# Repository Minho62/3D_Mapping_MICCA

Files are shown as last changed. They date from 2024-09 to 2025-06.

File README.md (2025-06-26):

# 3D라이다를 활용한 지형 측량 디바이스

## 목차
1. [프로젝트 소개](#프로젝트-소개)
2. [개발환경](#개발환경)
3. [DIRECTORY TREE](#directory-tree)
4. [주요 함수별 기능](#주요-함수별-기능)
5. [Flow chart](#flow-chart)
6. [H/W](#hw)
7. [F/W](#fw)
8. [SW구성](#sw구성)
9. [기능설계도](#기능설계도)
10. [RESULT](#result)

----------

## 프로젝트 소개
- 이 디바이스는 3D라이다(LIDAR)와 관성측정장치(IMU)를 활용하여 지형 데이터를 수집하는 혁신적인 도구입니다. 이를 통해 정확하고 상세한 지형 정보를 제공합니다. 디바이스는 두 가지 측정 방식을 지원합니다.
    - 2D 단면 데이터 측정: 라이다 센서를 통해 특정 단면의 2차원 데이터를 수집하여 해당 구역의 상세한 정보를 제공합니다. 이는 특정 구역의 높낮이와 형태를 명확하게 파악하여 2D 도면으로 나타내어 줍니다.
    - 3D 데이터 측정: 라이다와 IMU를 결합하여 지형의 3차원 데이터를 생성합니다. 이를 통해 지형의 전체적인 구조와 특징을 입체적으로 파악할 수 있습니다. 필요시, 해당 공간의 체적을 구할 수 있습니다.
- 또한, 디바이스는 두 가지 모드로 측정을 수행할 수 있습니다.
    - 차량 모드: 디바이스를 4륜 차량에 장착하여 블루투스로 조작할 수 있습니다.
    - 셀카 모드: 좁은 내부 공간 등 차량이 들어가기 어려운 구역을 사람이 직접 손으로 들고 측정할 수 있습니다.
- 이 디바이스는 건설, 토목 공사, 상하수도 점검, 아파트(오피스텔) 내부 측량 등에 활용될 수 있습니다.

https://github.com/user-attachments/assets/129de977-cf51-411d-8989-09c48eeaee29

----------

## 개발환경
- OS: Window10, Ubuntu 20.04, ROS Noetic
- Tool: VScode, JupyterNotebook, Arduino
- 프로젝트 관리:Notion, Github
- 회로: OrCad Capture
- PCB: PADS Layout

----------

## DIRECTORY TREE
```
.
├─Atmel/
│  ├─car/
│  │      car.ino
│  └─control_box/
│         control_box.ino
├─catkin_ws/
│  └─src/
│      ├─LIO-SAM-master/
│      ├─velodyne/
│      └─xsens_ros_mti_driver/
├─circuit/
├─doc/
├─img/
├─modeling/
└─source/
    │  main_3.py
    ├─CloudPoint2CAD/
    │  │  CloudPoint2CAD.ipynb
    │  └─USB/
    │      └─LOAM_PCD/
    ├─CloudPoints_representative_value/
    │     CloudPoints_representative_value.md
    ├─log/
    ├─USB/
    ├─volume/
    └─    volume.py

```

각 폴더와 파일에 대한 개요입니다:

| 폴더, 파일 | 설명 |
| --- | --- |
| `Atmel/` | Jetson Orin Nano와 통신, XM430-W210-T(모터), Control Box, 4륜 자동차, Atmega2560을 제어하기 위한 Atmel 소스 |
| `car.ino` | 4륜 자동차 제어를 위한 소스 |
| `control_box.ino` | Control Box를 이용해 Jetson Orin Nano와 Serial 통신을 위한 소스 |
| `catkin_ws/` | ROS Workspace|
| `src/` | ROS Workspace의 src 폴더 |
| `LIO-SAM-master/` | 3D Mapping을 위한 LIO SAM 알고리즘 |
| `velodyne/` | VLP-16(Lidar)을 사용하기 위한 소스 |
| `xsens_ros_mti_driver/` | XSENSE MTi-G-710-6A8G4(IMU)를 사용하기 위한 소스 |
| `circuit/` | F/W를 제어하기 위한 회로도 |
| `doc/` | 참고한 데이터셋, 자료 |
| `img/` | 프로젝트 수행 이미지 |
| `modeling/` | 모델링 이미지 |
| `source/` | 3D Mapping, 측정 데이터 처리를 위한 폴더 |
| `mian_3.py` | 3D Mapping, 측정 데이터 처리를 위한 소스 |
| `CloudPoint2CAD/` | Cloud Point를 CAD파일로 변환, 테스트 폴더 |
| `CloudPoint2CAD.ipynb` | 수집한 Cloud Point를 2D 단면으로 나타내 DXF 파일로 변환하는 소스 |
| `CloudPoints_representative_value/` | 3D Mapping 후 Cloud Points 전처리 자료 |
| `CloudPoints_representative_value.md` | 3D Mapping 후 CloudCompare를 활용한 Cloud Points의 대표 좌표값 추출 방법|
| `log/` | 'mian_3.py'의 log |
| `USB/` | 기록된 Ros Bag 파일, Cloud Point data, 데이터 처리 파일을 저장하기 위한 경로(삽입한 USB 경로) |
| `volume/` | 3D체적을 구하는 경로 |
| `volume.py` | Cloud Points의 대표 좌표값 추출 후 3D 체적을 구하는 소스 |

----------

## 주요 함수별 기능
### main_3.py

| 함수, 클래스 | 설명 |
| --- | --- |
| `SERIAL` | 시리얼 포트를 통해 JetsonOrinNano와 Arduino간의 통신을 관리 |
| `socket_isOpen` | 지정된 호스트(Lidar VLP16)가 네트워크에서 활성 상태인지 확인하여, 연결 가능하면 True를 반환|
| `read_6D_PCDFile` | 맵핑 이후, PCD 파일을 읽어 XYZ 좌표, 강도(intensity), 회전(roll, pitch, yaw) 및 시간을 배열로 반환 |
| `slice_points2img` | 3D 포인트 클라우드를 주어진 평면의 법선 벡터에 투영하여 2D 평면에 XY 좌표로 변환한 배열을 반환 |
| `LIO_SAM` | LIO-SAM 프로세스를 관리하고 데이터를 처리, 여러 측정 모드들을 실행시키고 관리 |
| `change_lio_param` |  LIO-SAM의 설정 파일을 수정하여 PCD 파일 저장 위치를 업데이트 |
| `stop` | 현재 실행 중인 LIO-SAM 및 ROS BAG 프로세스를 중지 |
| `send_process_data` | 현재 프로세스의 진행 상태를 시리얼로 전송 |
| `cave_mode` | 동굴(CAVE) 측정 모드(모든 진행경로를 Mapping하는 모드)에서 데이터를 처리하고 ROS BAG 기록을 시작 |
| `processing` | 터널(TUNNEL) 측정 모드(측정 장비를 90도로 회전 후, 평면을 Scan하는 모드)에서 ROS BAG 기록을 시작 후 3D 좌표 데이터를 처리하여 2D로 나타냄 |
| `SERIAL_DATA_PROC` | 시리얼 데이터를 분석하여 상태를 업데이트하고, 들어오는 명령을 처리 |
| `SBC_CONTROL` | JetsonOrinNano, Arduino, LiDAR, IMU, Battery, USB 장치의 연결 상태를 모니터링하고, 필요에 따라 해당 장치와 상호작용 |
| `get_usb_stat` | 연결된 USB 장치의 정보를 반환 |
| `is_usb_device` | 주어진 장치가 USB 장치인지 확인하고, USB 장치일 경우 True를 반환 |
| `new_get_mount_points` | 현재 마운트된 USB 장치들의 정보를 반환 |\
| `arduino` | 아두이노 장치를 탐색하여 연결하고, 상태를 업데이트 |
| `lidar` | LiDAR 장치의 네트워크 연결 상태를 확인하고, 연결 여부에 따라 ROS 노드를 실행 또는 종료 |
| `imu` | IMU 장치의 USB 연결 상태를 확인하고, 연결 여부에 따라 ROS 노드를 실행 또는 종료 |
| `search_usb` |  USB 장치의 연결 상태를 확인하고, 아두이노에 USB 연결 상태를 알림 |
| `mount_usb` | 시스템에 연결된 USB 장치를 마운트 |
| `umount_usb` |  시스템에서 USB 장치를 언마운트하고 안전하게 연결을 해제 |
| `emergency_stop` | 비상 정지 명령이 내려졌을 때, 모든 프로세스를 종료하고 시스템을 셧다운 |
| `state` |  LiDAR, IMU, USB 장치가 모두 연결되어 있는지 상태를 반환 |

----------

## Flow chart
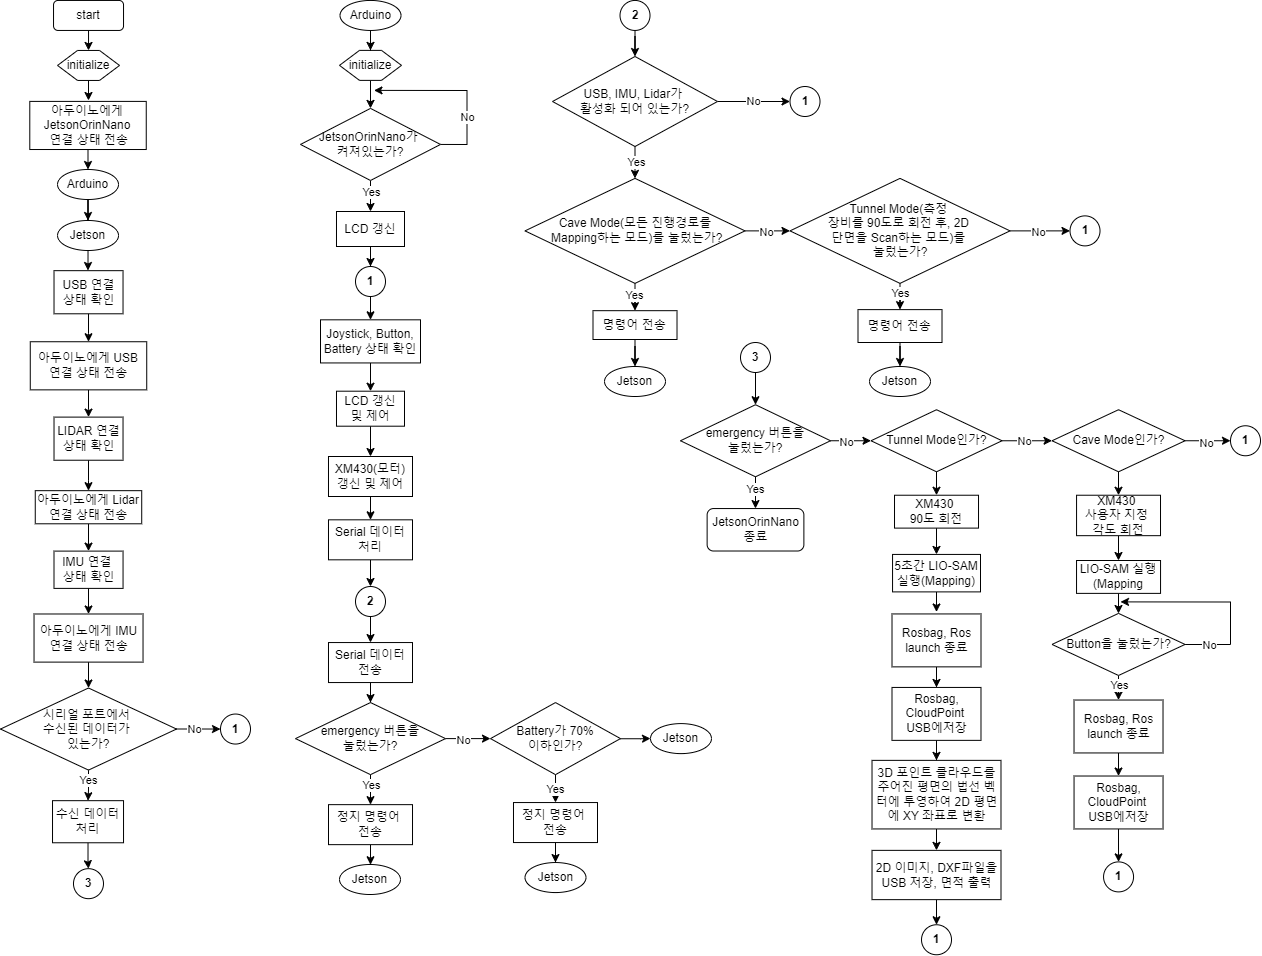
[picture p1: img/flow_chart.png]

  
----------

## H/W
- Fusion 360을 통해 모델링
- 3D 프린터를 통해 제작

MODELING             |  REAL
:-------------------------:|:-------------------------:
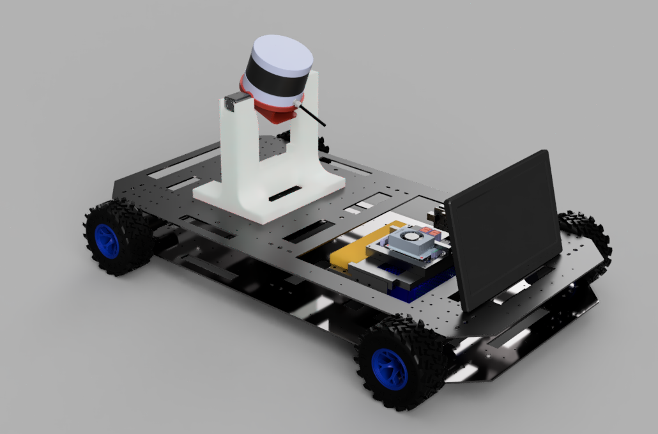
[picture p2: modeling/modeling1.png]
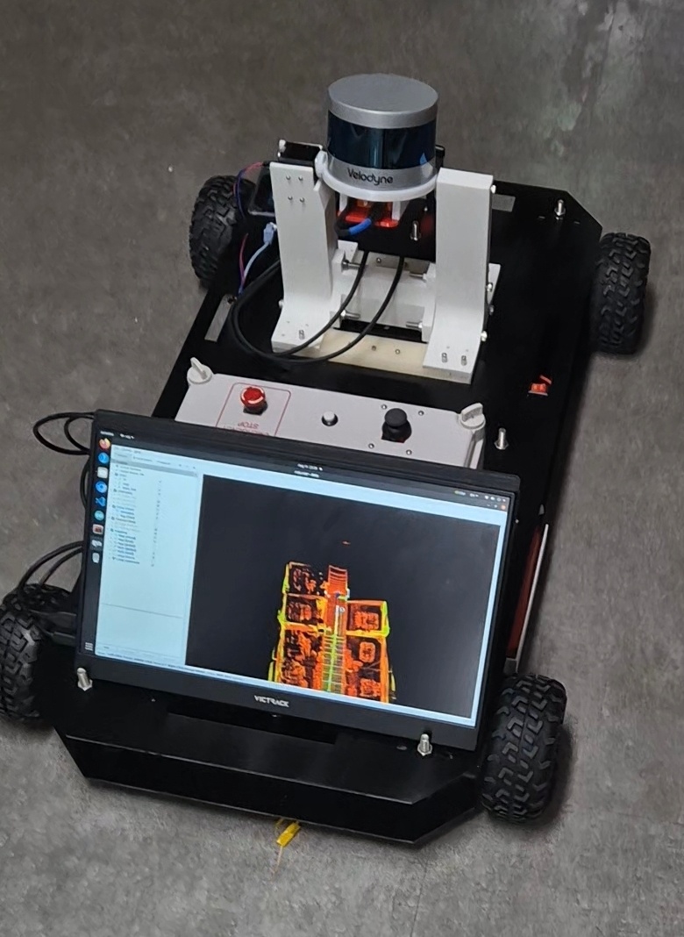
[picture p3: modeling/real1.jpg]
  |  
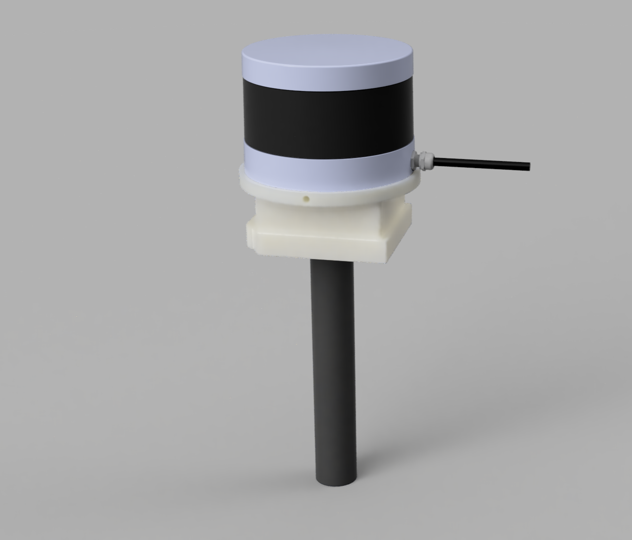
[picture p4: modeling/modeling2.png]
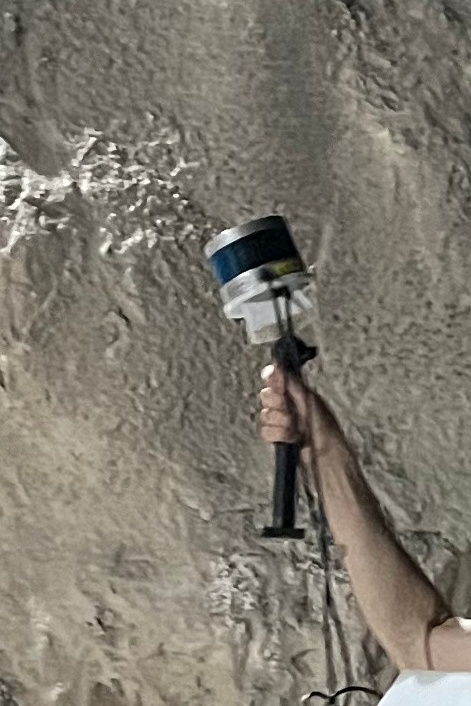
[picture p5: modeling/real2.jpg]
  |  
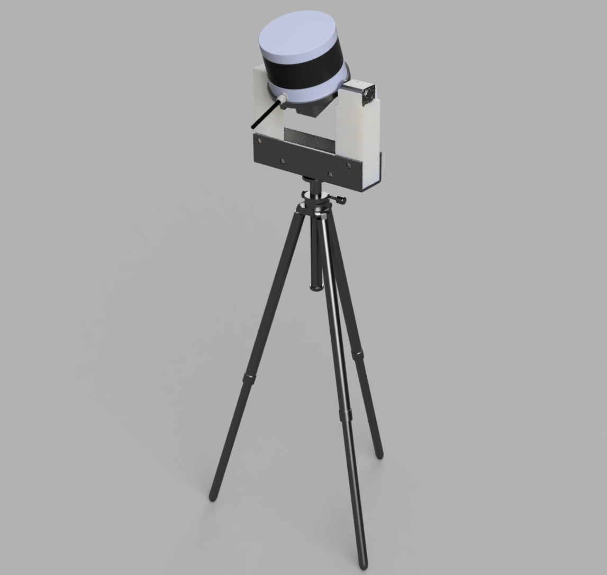
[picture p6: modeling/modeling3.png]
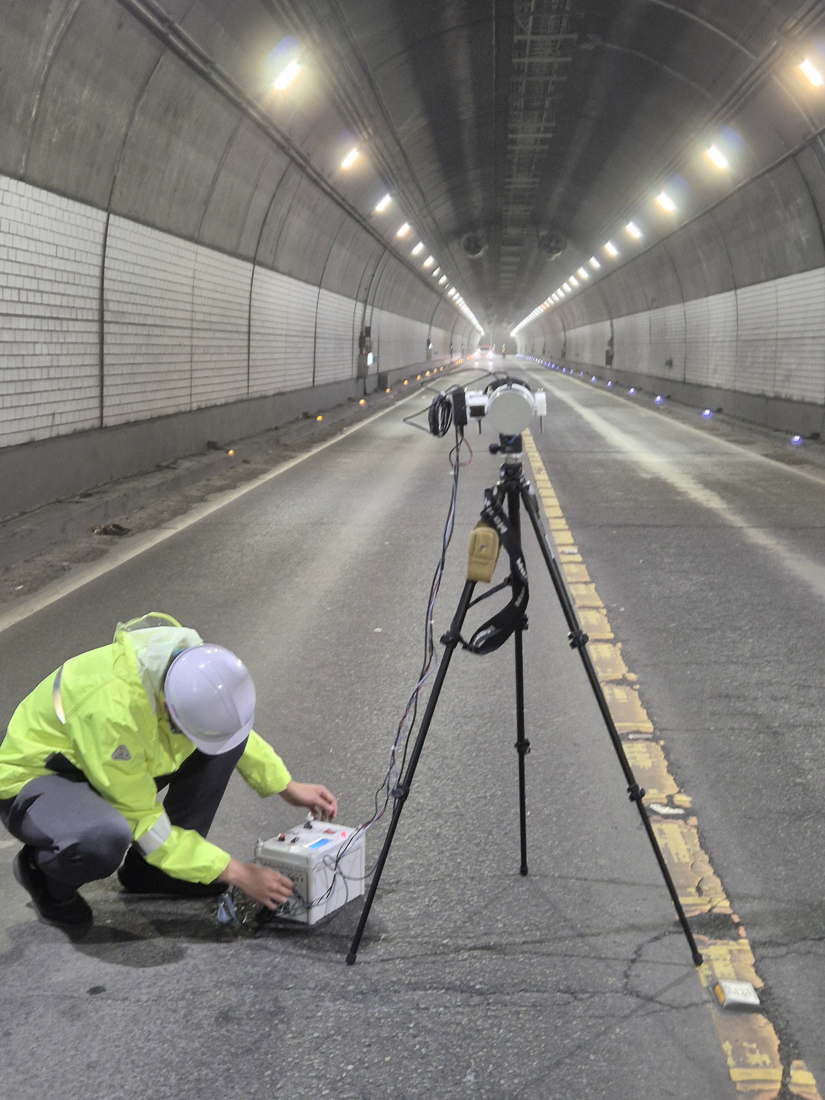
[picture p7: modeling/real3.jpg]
  |  

----------

## F/W
- 블럭도
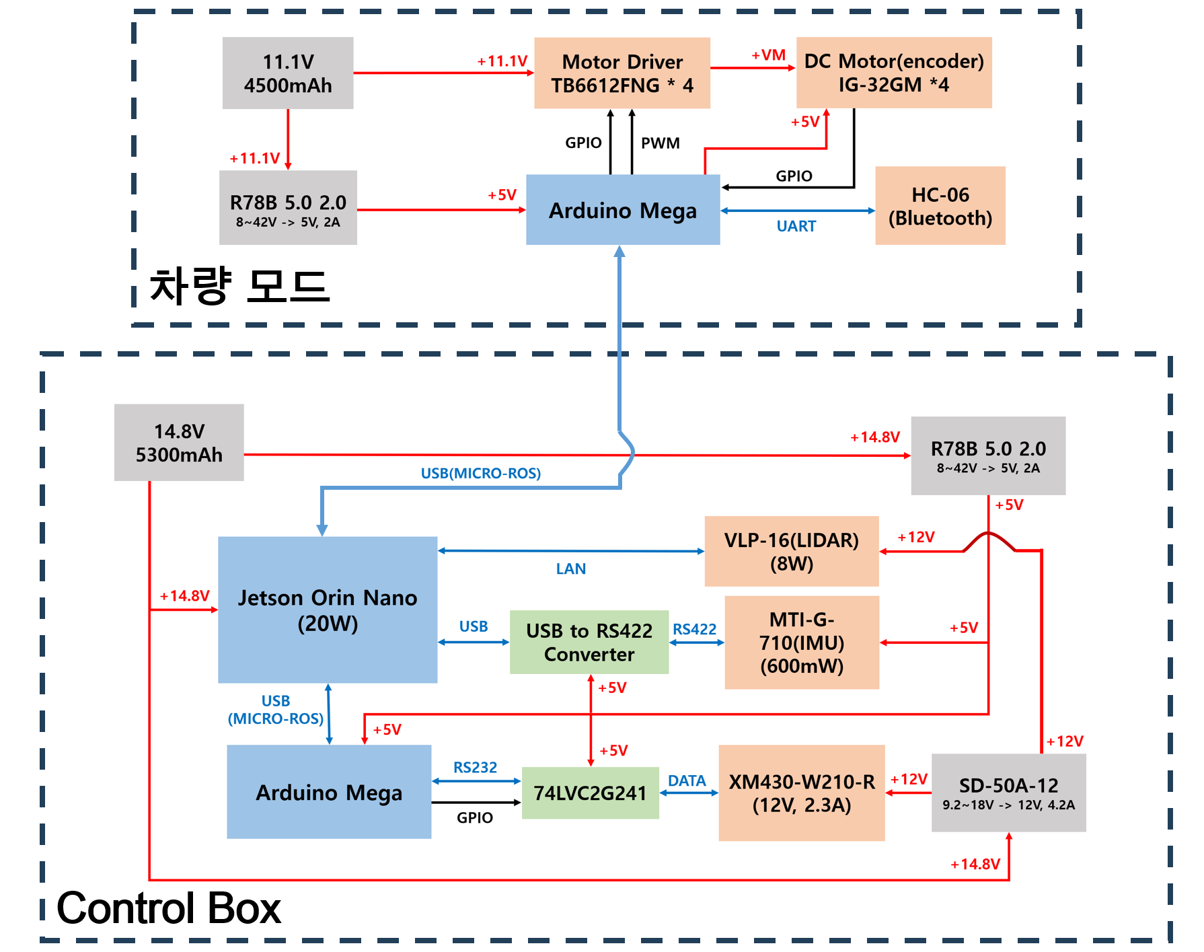
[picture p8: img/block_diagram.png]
    

- Control Box
    - 회로도
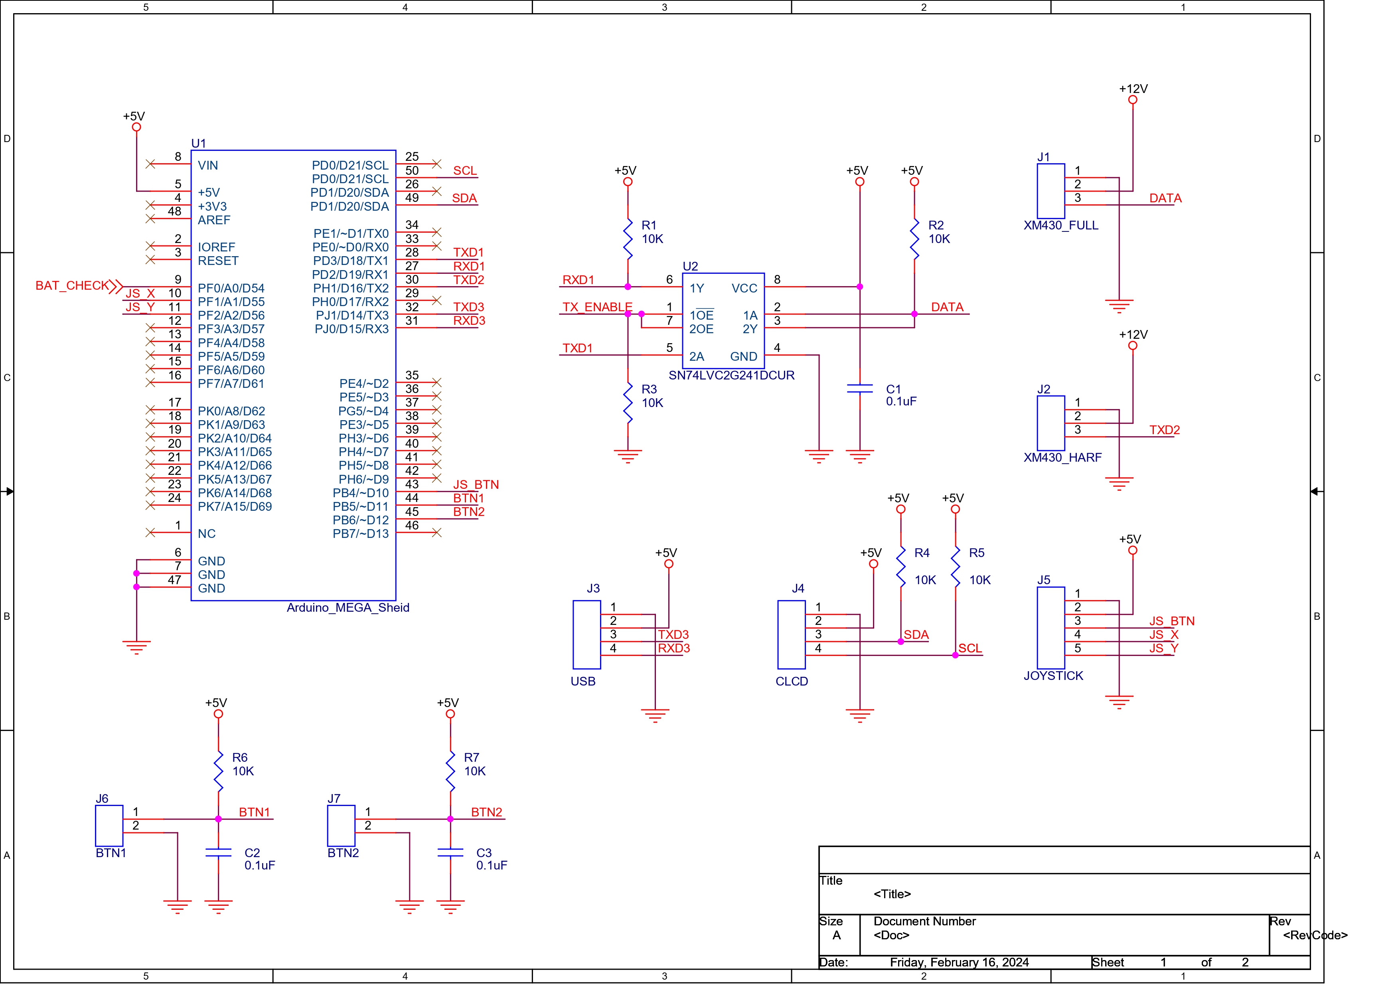
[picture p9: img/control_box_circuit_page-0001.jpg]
        
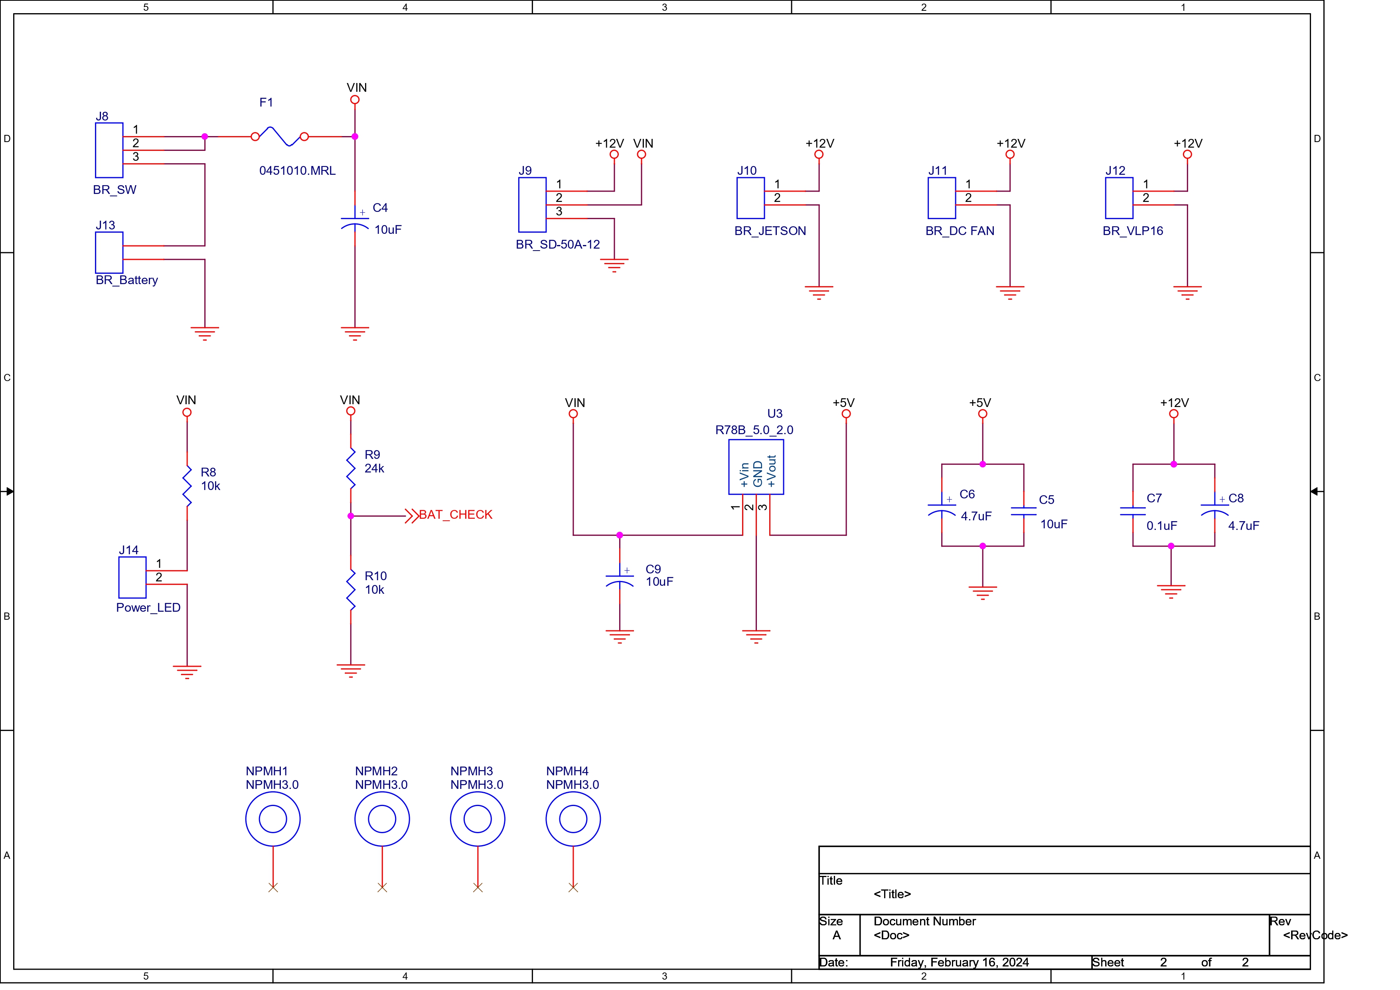
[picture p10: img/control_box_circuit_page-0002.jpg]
        
    - PCB
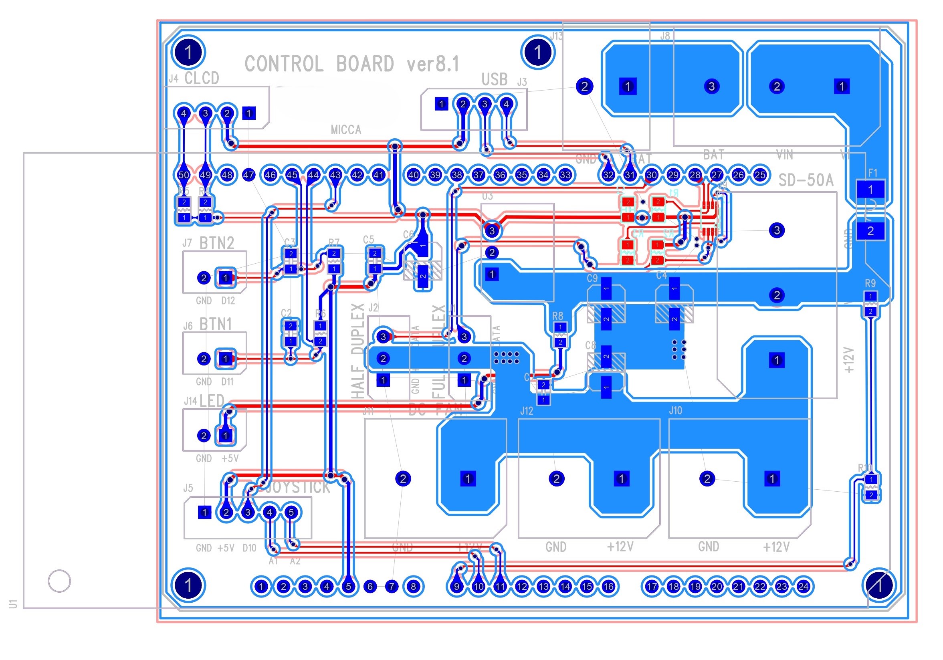
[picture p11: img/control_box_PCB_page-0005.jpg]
        
- 차량 모드
    - 회로도
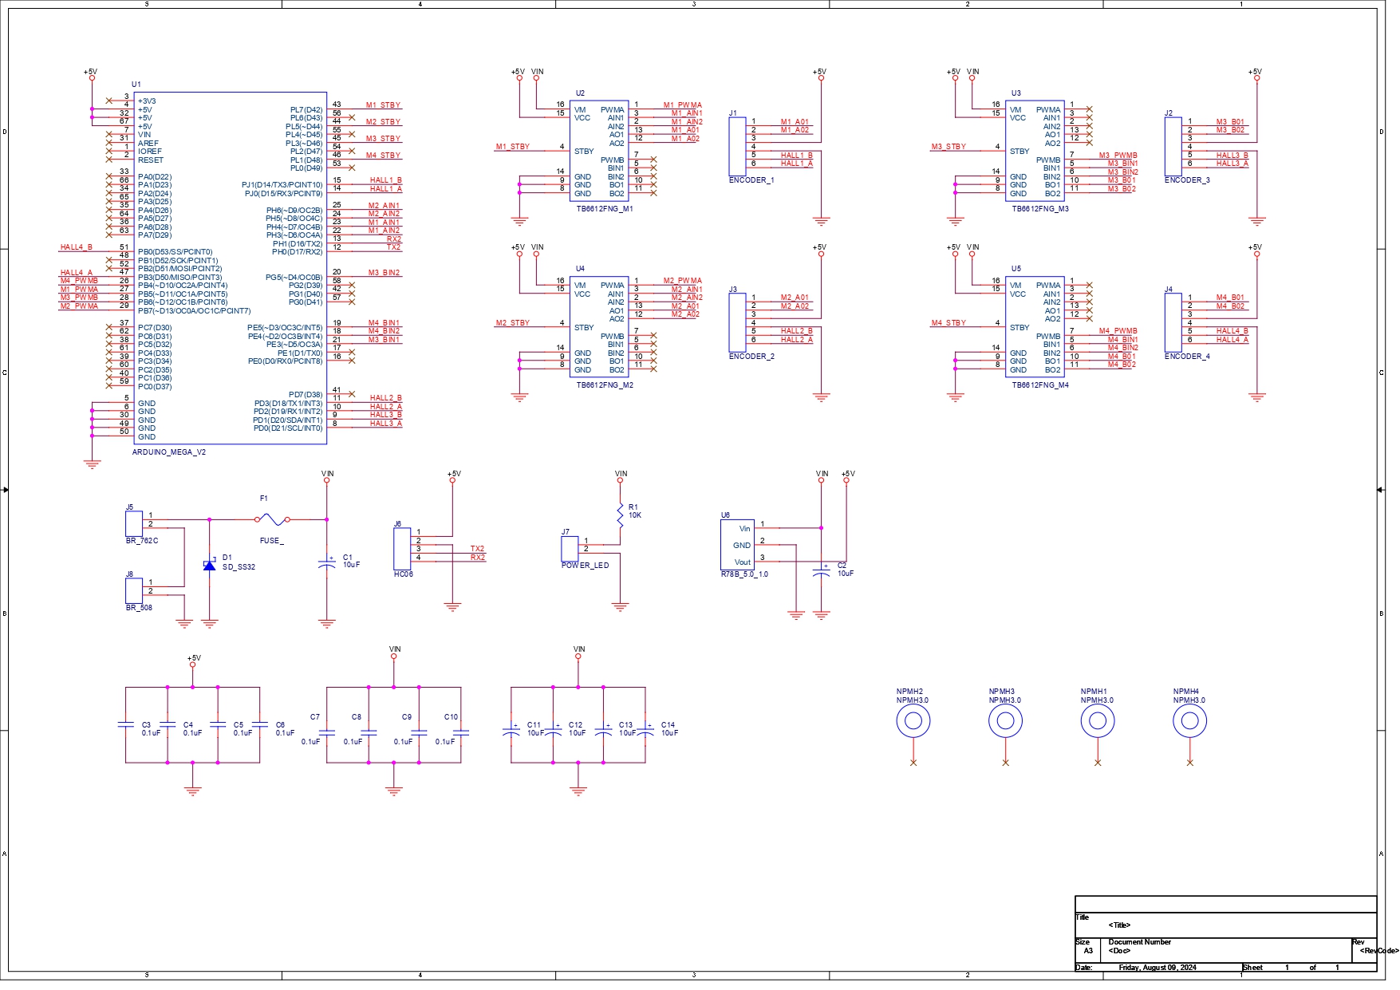
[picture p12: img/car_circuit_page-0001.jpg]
        
    - PCB
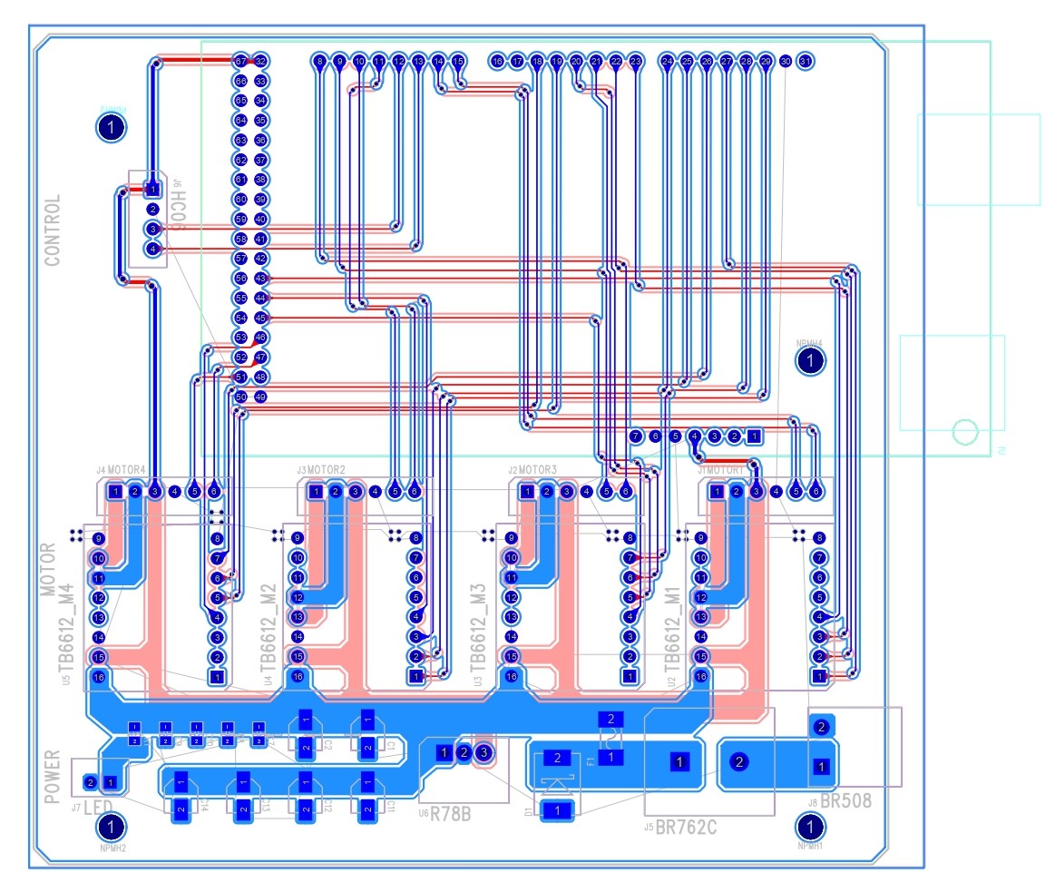
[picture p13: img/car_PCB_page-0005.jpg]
        

----------

## S/W구성
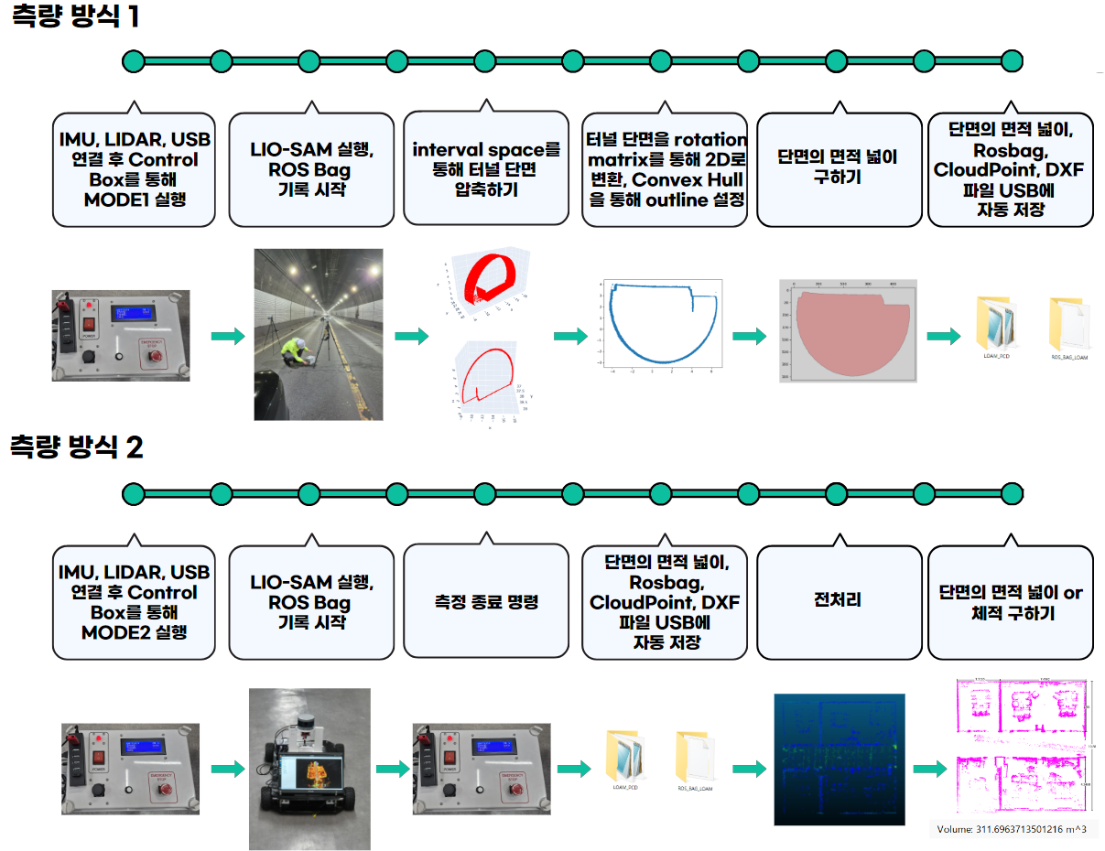
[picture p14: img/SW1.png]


----------

## 기능설계도
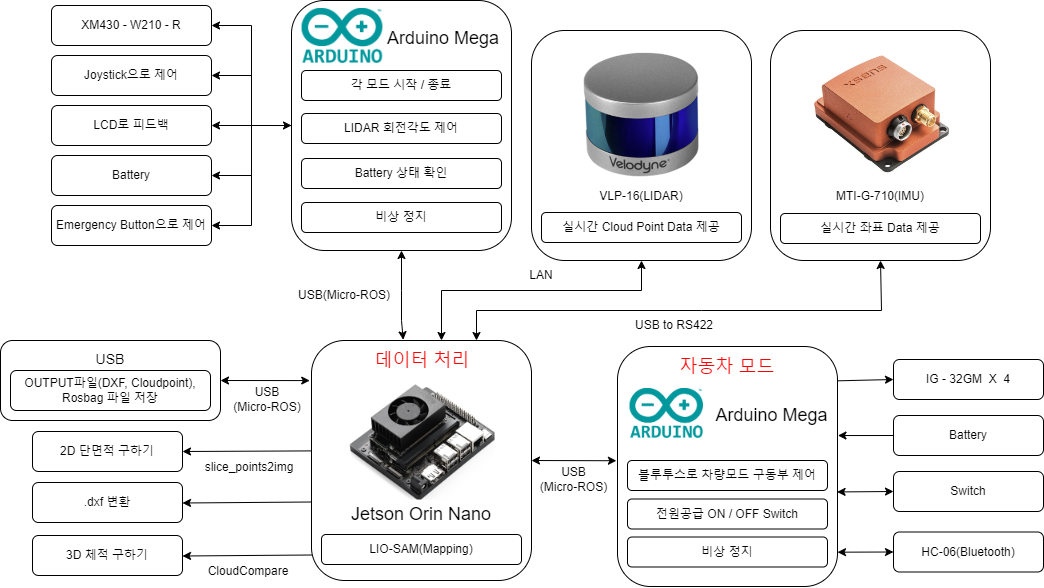
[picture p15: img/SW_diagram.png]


----------

# RESULT

## Tunnel

Real             |
:-------------------------:|
 |

Scan             |  DXF
:-------------------------:|:-------------------------:
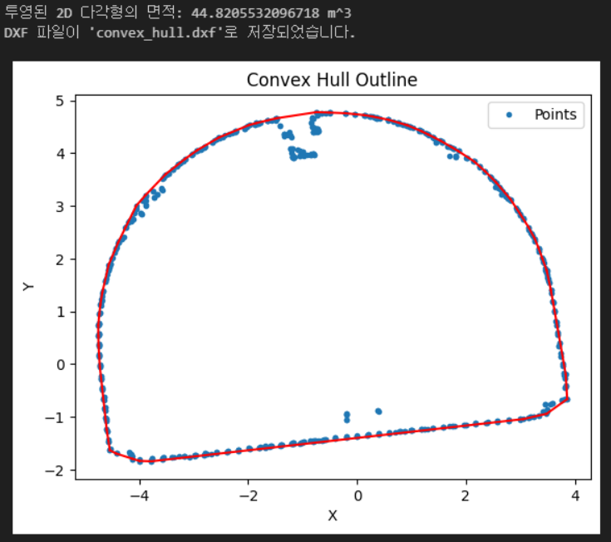
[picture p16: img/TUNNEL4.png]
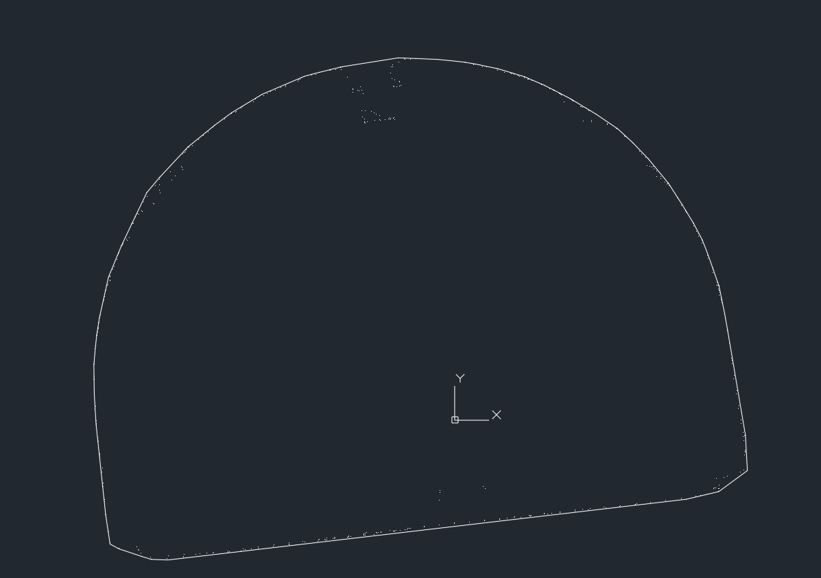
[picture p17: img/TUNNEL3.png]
  |  

----------

## Cave

Real            |  Scan
:-------------------------:|:-------------------------:
<video src = "https://github.com/user-attachments/assets/7dc2f852-dbb4-49e8-8e83-06cb473ff6c9"> |  <video src = "https://github.com/user-attachments/assets/3b821411-f0cc-4dca-8465-04873961ad4c" width="20%" height="20%"> 

----------

## 건축물 2D 단면

Real             |
:-------------------------:|
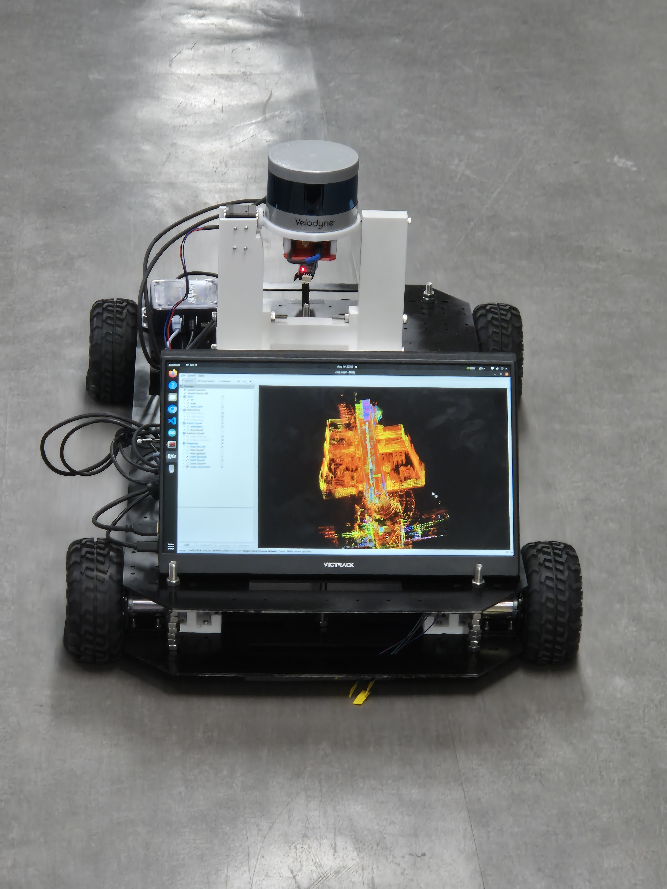
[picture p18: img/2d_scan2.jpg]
 |

실제 설계 단면             |  Scan
:-------------------------:|:-------------------------:
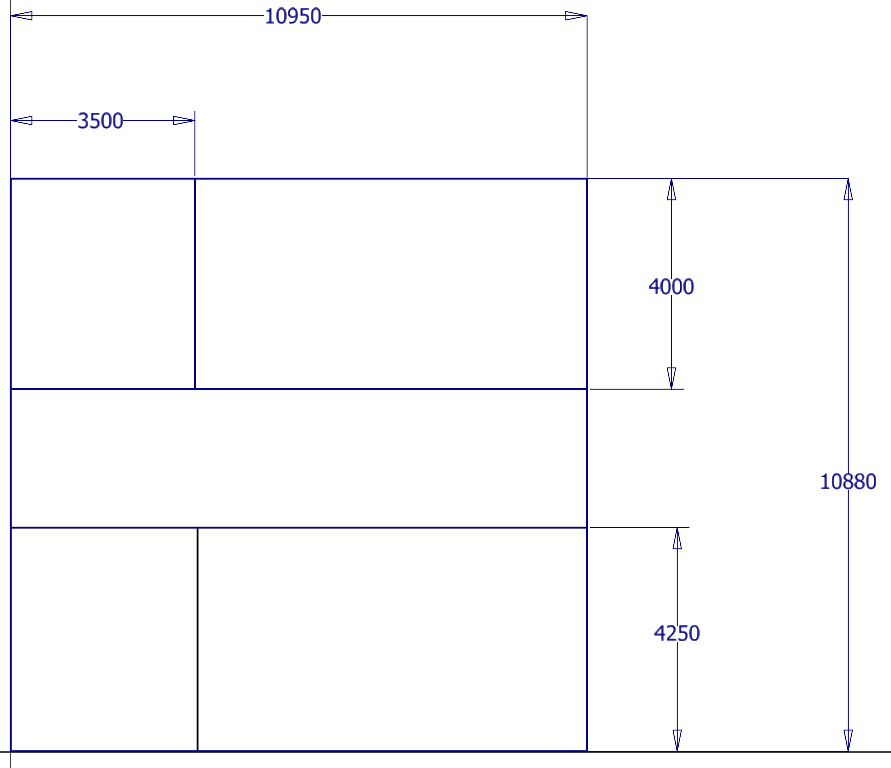
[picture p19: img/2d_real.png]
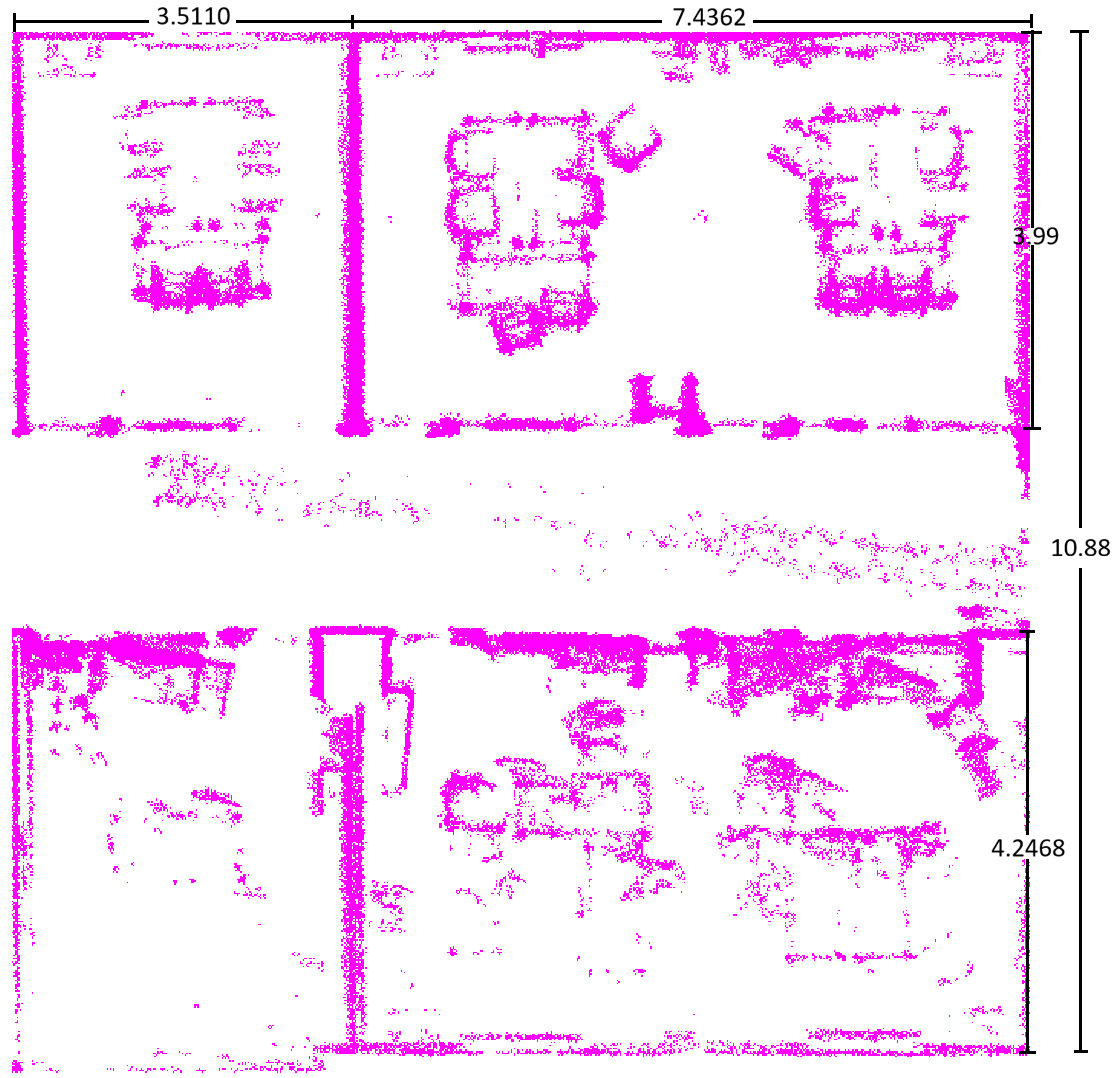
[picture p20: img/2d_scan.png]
  |  
실제 설계 넓이 : 119.136㎡	 |  Scan 넓이 : 119.09248㎡

오차율 : 0.037% 

----------

## 건축물 3D 체적

Real             |
:-------------------------:|
 |

실제 설계 단면             |  Scan
:-------------------------:|:-------------------------:
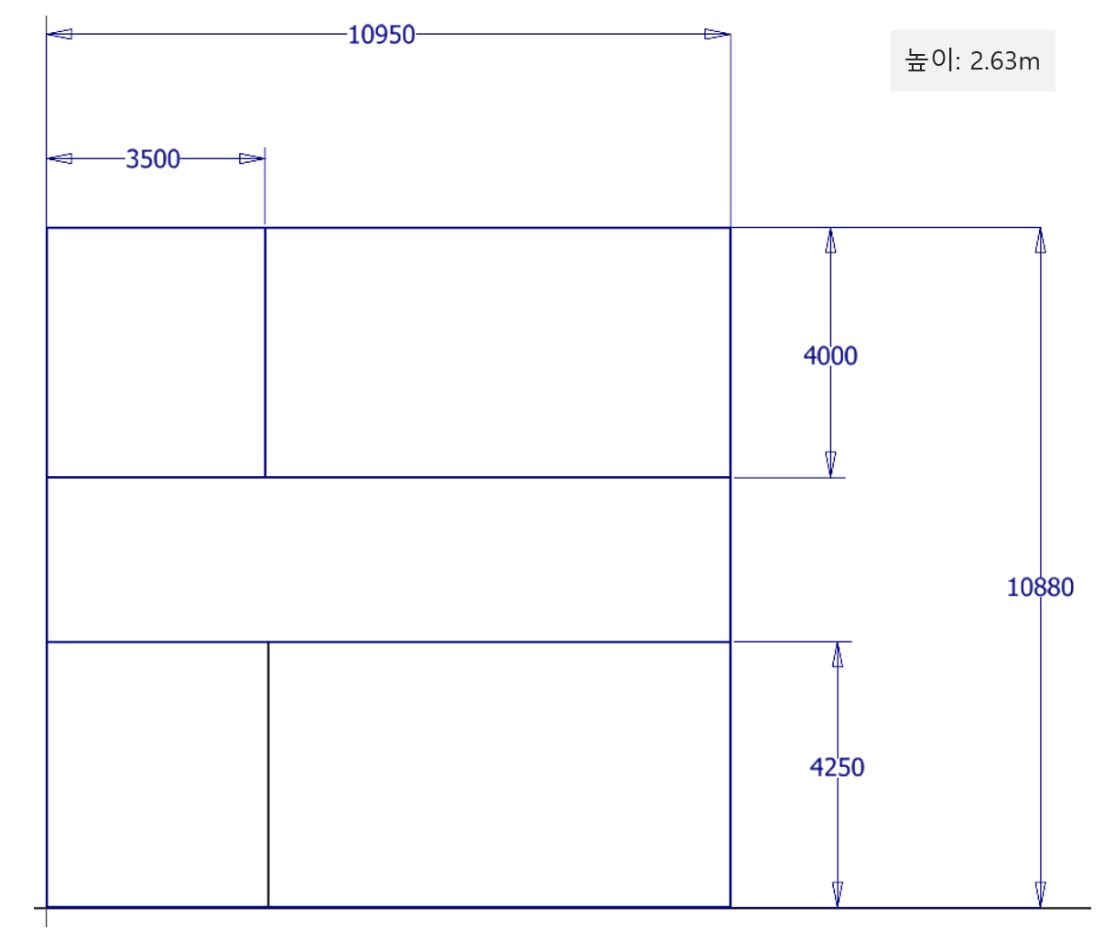
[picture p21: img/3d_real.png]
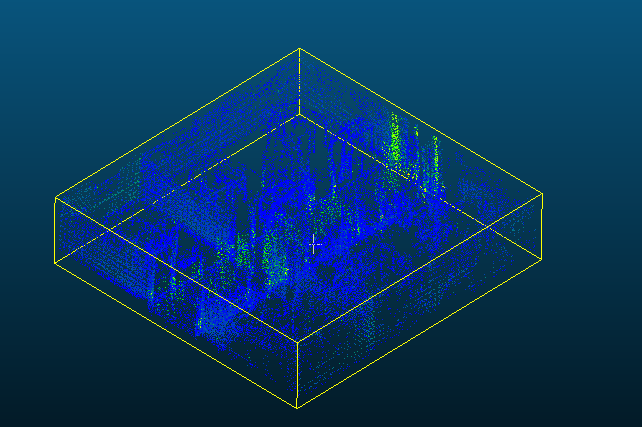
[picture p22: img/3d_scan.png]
  |  
실제 설계 체적 : 313.32768m³	 |  Scan 체적 : 311.6963713501216m³

오차율 : 0.523%

----------

## Road

Real            |  Scan
:-------------------------:|:-------------------------:
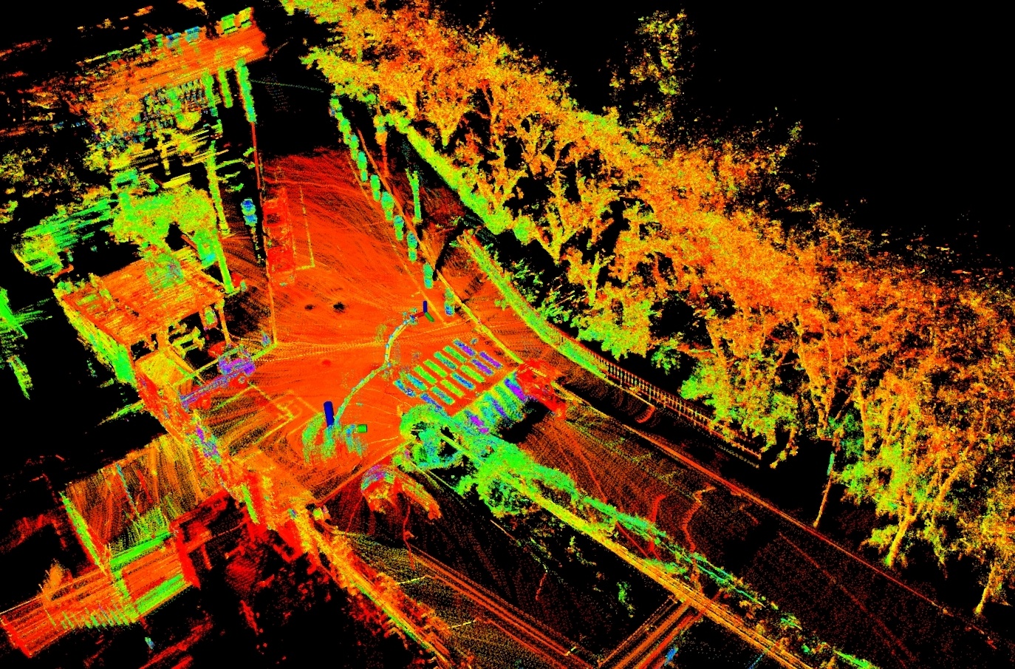
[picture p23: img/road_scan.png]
<video src = "https://github.com/user-attachments/assets/0827d623-0713-4f08-83b8-101b94800f4f"> |   

----------

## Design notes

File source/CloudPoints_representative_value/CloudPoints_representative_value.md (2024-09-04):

# CloudCompare를 활용한 대표 좌표값 추출 방법(전처리)

 **이민호**

[CloudCompare v2.6.1 - User manual.pdf](CloudPoints_representative_value/CloudCompare_v2.6.1_-_User_manual.pdf)

---

1. 파일 ➡️ 열기 ➡️ ‘cloudGlobal.pcd’ **파일 열기**

---

1. **좌표 축 정렬**
우측 하단 밑의 좌표계 참고 → 포인트들의 좌표 축이 정렬되어 있지 않음
    
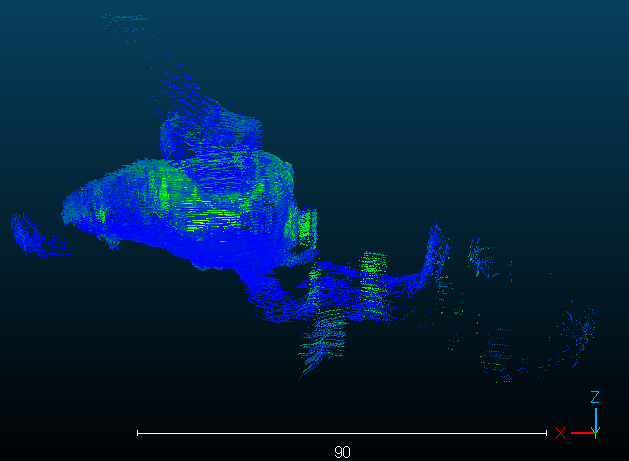
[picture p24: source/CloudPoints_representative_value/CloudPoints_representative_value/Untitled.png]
    
    
    ➡️ 구름 아이콘 클릭 
    
    
    
    ➡️ 상단 메뉴 바에서 회전 클릭
    
    
    
    ➡️ 좌측 메뉴 바에서 도형을 클릭하면 내가 원하는 평면을 볼 수 있게 해줌.
    
    
    
    ➡️ 각각의 평면을 확인하고, 회전하고자 하는 축을 선택
    ➡️ 축 선택 후 회전 각도 입력( 많이 회전 → 큰 각도 / 정밀하게 → 작은 각도)
    
    윗칸 회전      :  축 회전
    아랫칸 회전  :  평면 이동
    
    ➡️ 백워드 or 전방을 눌러 회전시켜 회전 축을 정렬한다. 마우스로도 회전 가능
    
    ➡️ 정렬 완료 후 초록색 체크 클릭
    
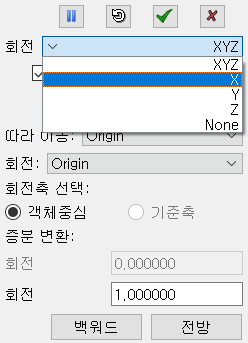
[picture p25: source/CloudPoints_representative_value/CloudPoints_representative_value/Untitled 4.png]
    
    
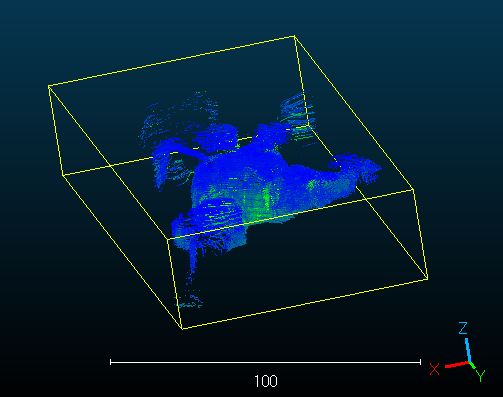
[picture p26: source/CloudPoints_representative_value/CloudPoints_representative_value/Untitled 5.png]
    
    
    Boundary 박스와 함께 축이 잘 정렬 된 것을 알 수 있다.

---

1. **Region Of Interest - 원하는 단면 자르기**
    
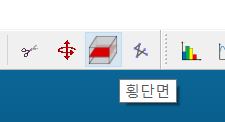
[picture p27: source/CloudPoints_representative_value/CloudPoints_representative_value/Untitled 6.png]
    
    
    ➡️ 구름 아이콘 클릭 ➡️ 횡단면 클릭 ➡️ 원하는 크기로 잘라서 얻는다(좌측 메뉴바 - 평면 클릭 후 자르면 더욱 편함)
    
    
    
    화살표 끝 : 앞뒤로 자름
    
    동그라미 링 : 해당 축을 기점으로 회전시킴
    
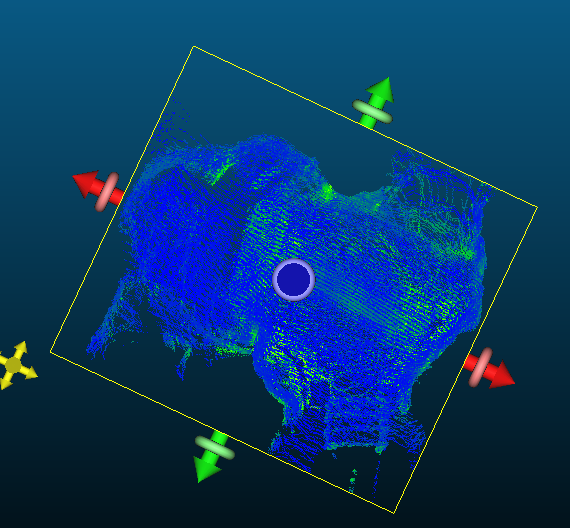
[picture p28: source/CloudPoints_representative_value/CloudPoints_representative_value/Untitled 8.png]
    
    
    ➡️ 최종 범위 지정 후 해당 아이콘 클릭
    
    
    
    ➡️ 새로운 포인트들이 생김 ➡️ 이전 포인트 체크 해제
    
    

---

1. **쓰레기 좌표 값 필터링 (선택 사항)**
    
    
    
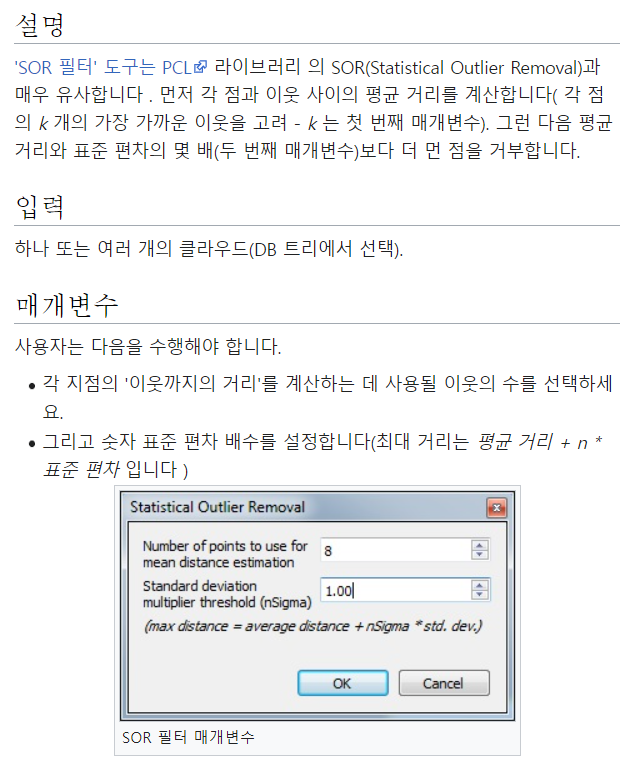
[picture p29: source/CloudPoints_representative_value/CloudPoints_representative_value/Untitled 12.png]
    

---

1. **대표 면 잘라내기**
➡️ 최종 section만 클릭
    
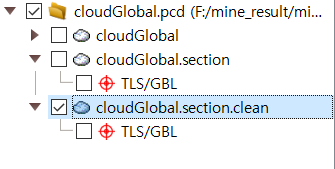
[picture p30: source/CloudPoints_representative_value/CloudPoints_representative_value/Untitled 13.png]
    
    
    ➡️ 최종 section만 클릭
    
    
    
    ➡️ 횡단면 클릭
    
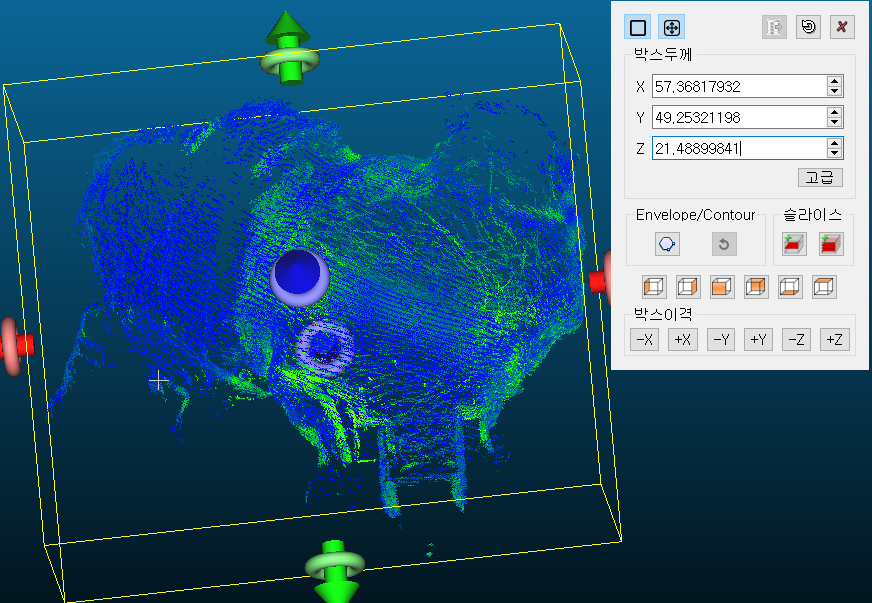
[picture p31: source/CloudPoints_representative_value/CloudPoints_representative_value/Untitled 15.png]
    
    
    ➡️ X축을 기준으로 분할 ➡️ X축 슬라이싱 단면 두께 설정 (EX : 1m)
    
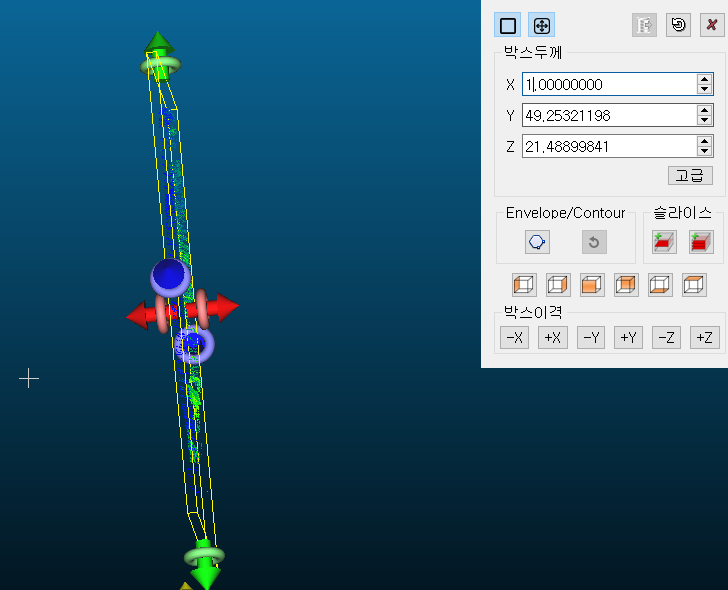
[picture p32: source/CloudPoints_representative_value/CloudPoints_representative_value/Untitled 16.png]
    
    
    ➡️ 오른쪽 아이콘 클릭
    
    
    
    ➡️ 슬라이싱 간격 갭 설정 (EX : 3m)
    
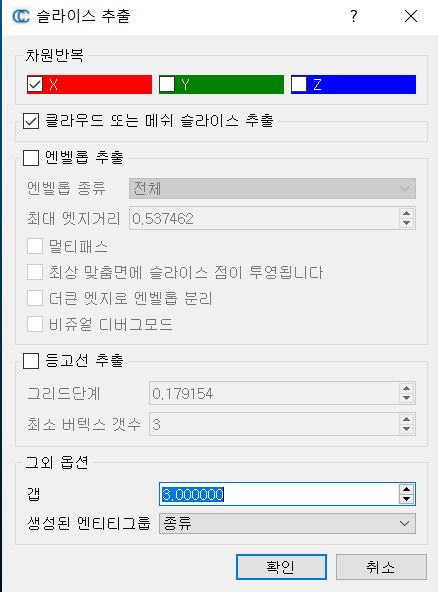
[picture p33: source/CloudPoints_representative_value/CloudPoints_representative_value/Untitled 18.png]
    
    
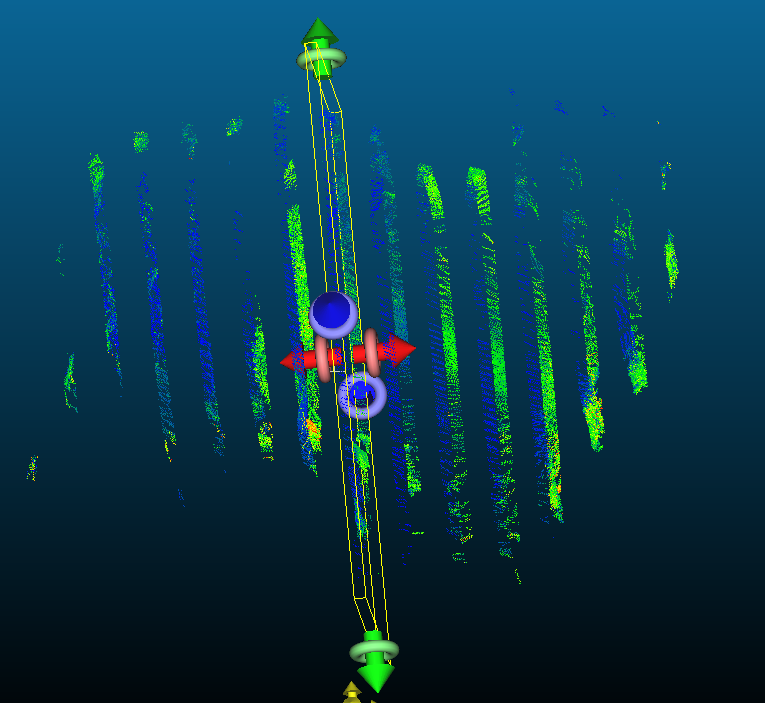
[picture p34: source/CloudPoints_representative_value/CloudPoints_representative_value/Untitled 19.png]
    
    
    ➡️ 좌표 초기화
    
    
    
    ➡️ Y축을 기준으로 분할 ➡️ Y축 슬라이싱 단면 두께 설정 (EX : 1m) ➡️ 반복
    
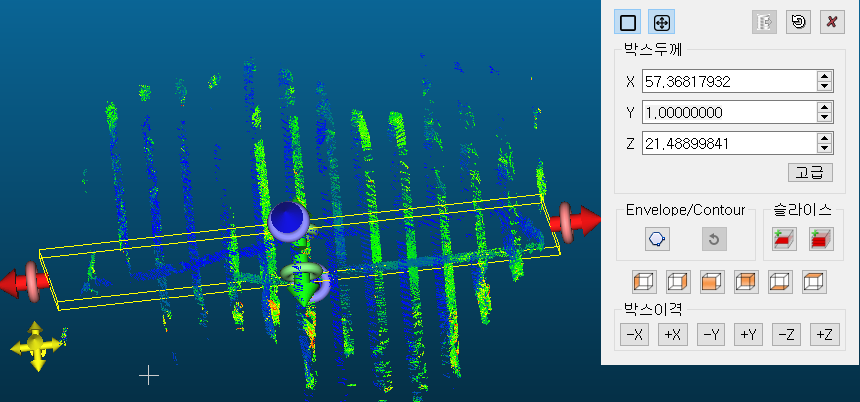
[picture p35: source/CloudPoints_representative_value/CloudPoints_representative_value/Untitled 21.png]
    
    
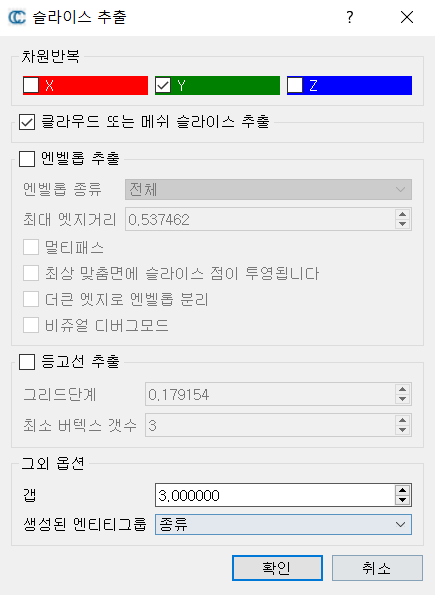
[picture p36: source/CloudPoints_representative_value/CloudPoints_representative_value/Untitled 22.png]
    
    
    ➡️ 해당 섹션 드래그 ➡️ 편집 ➡️ 병합 ➡️ 하나의 섹션으로 병합됨
    
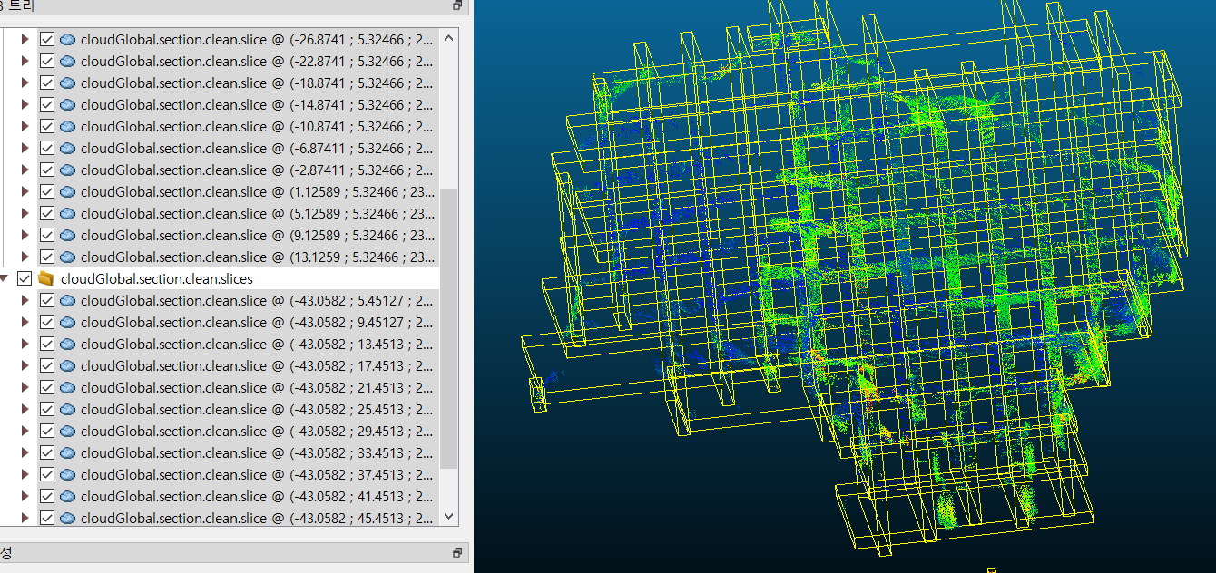
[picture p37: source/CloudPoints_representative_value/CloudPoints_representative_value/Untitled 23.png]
    
    
    
    
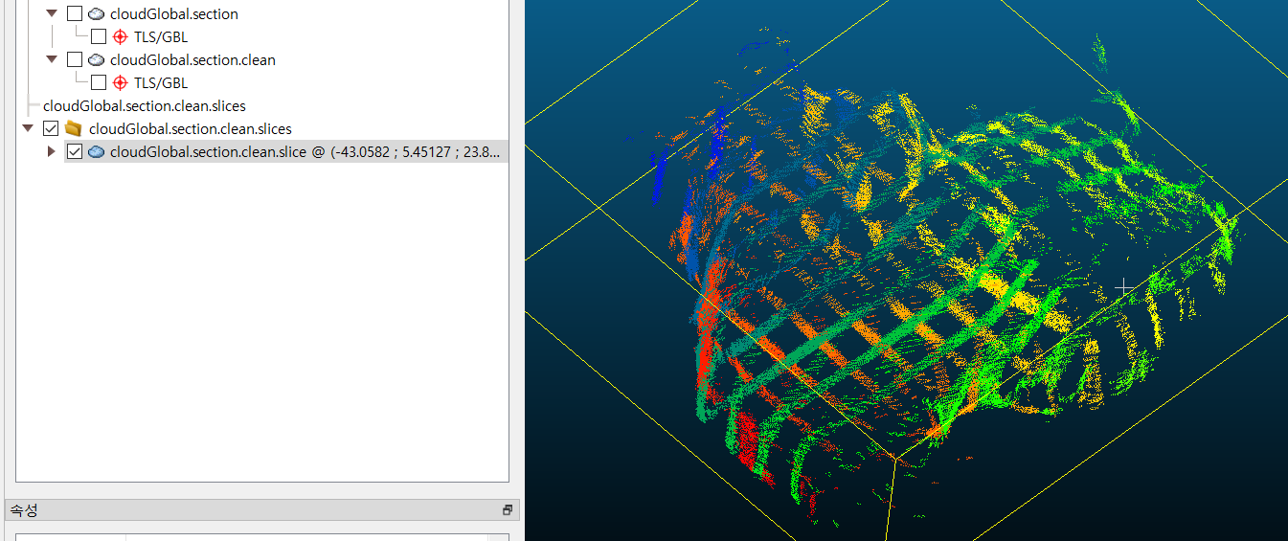
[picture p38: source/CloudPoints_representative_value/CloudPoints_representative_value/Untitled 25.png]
    

---

1. **대표 점 추출 (Down Sampling)**

➡️ 하위샘플 포인트클라우드 클릭
    

    
➡️ 방식 : Spatial ➡️ 점간 최소공간 설정 (EX :  3m) ➡️ 확인
    
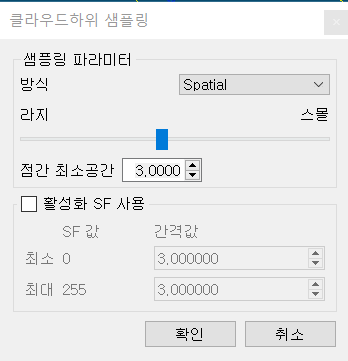
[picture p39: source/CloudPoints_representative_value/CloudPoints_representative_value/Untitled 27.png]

    
➡️ 점 크기 조절 (가시성 설정) ➡️ 이상유무 확인
    
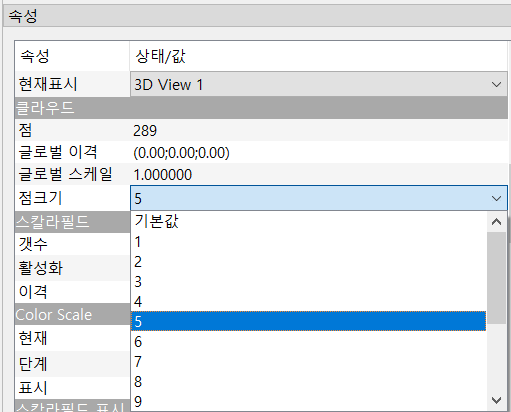
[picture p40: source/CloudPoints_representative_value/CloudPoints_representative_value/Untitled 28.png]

    
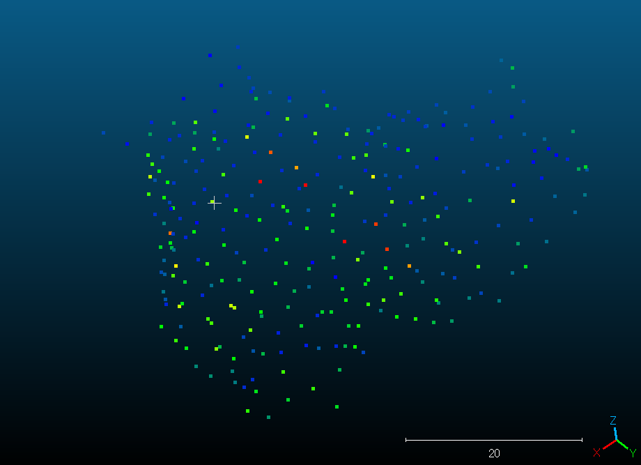
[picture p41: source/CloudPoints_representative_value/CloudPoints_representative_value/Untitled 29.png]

    
➡️ shift + 포인트 (마우스 왼쪽)클릭 ➡️ 좌표 값 나옴
    
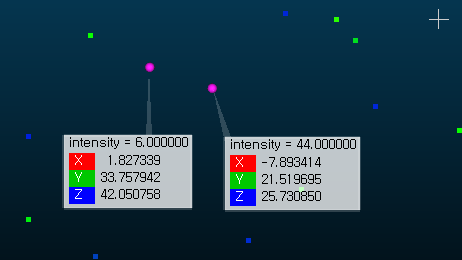
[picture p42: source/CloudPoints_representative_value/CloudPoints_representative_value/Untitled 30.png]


---

1. **엑셀 내보내기**

➡️ 최종 섹션 클릭 ➡️ 파일 ➡️ 저장  
    

    
➡️ 파일 형식 : ASCII cloud ➡️ 파일 이름 :  (이름).csv ➡️ 저장
    

    
➡️ 엑셀 기준 분리자 : comma ➡️ 컬럼 제목 클릭
    
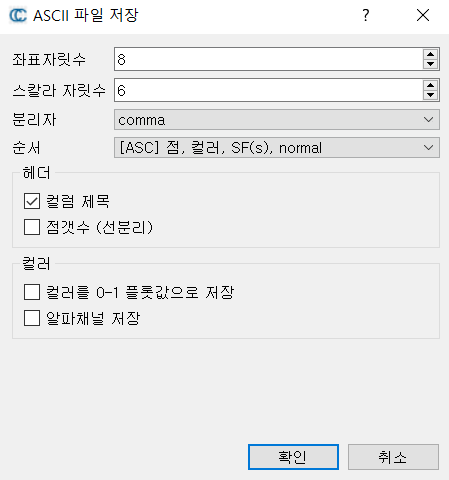
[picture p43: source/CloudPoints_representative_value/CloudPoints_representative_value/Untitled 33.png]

    
➡️ 엑셀 파일 확인 ( 차례대로 X좌표, Y좌표, Z좌표, 포인트 강도)
    
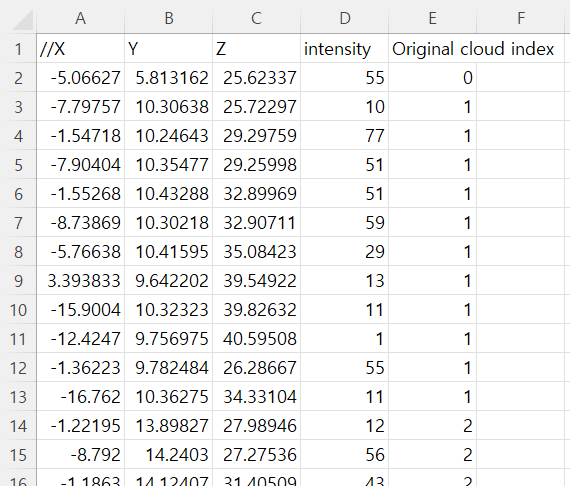
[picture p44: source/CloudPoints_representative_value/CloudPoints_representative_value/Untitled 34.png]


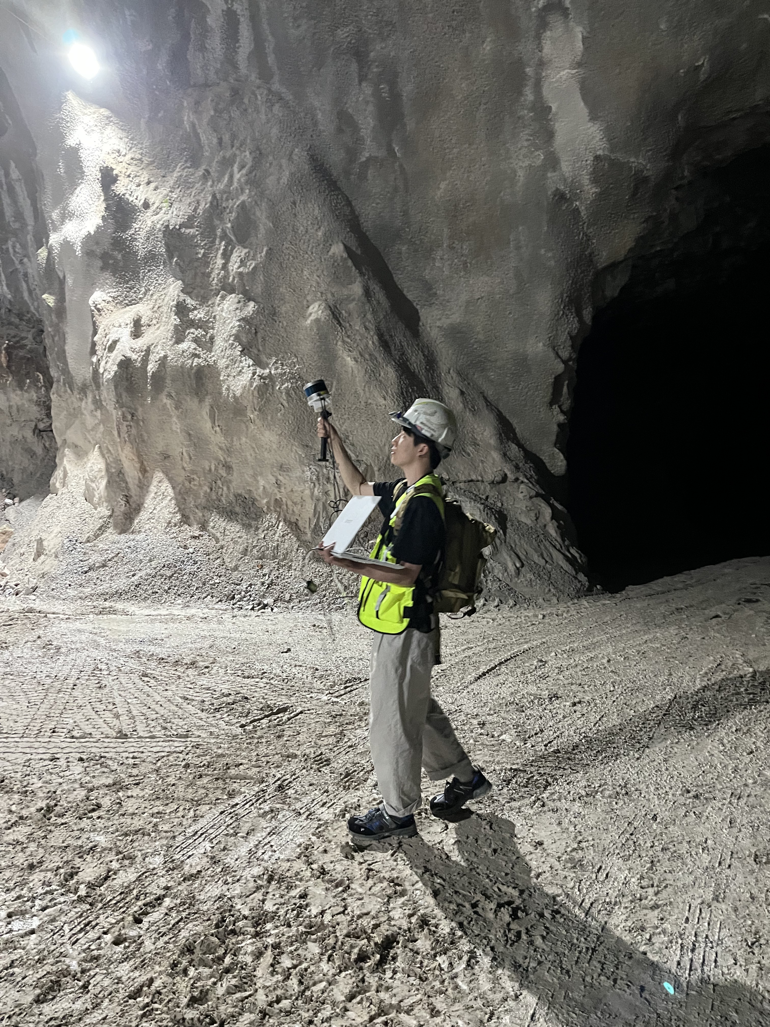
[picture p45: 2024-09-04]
img/CAVE1.jpg

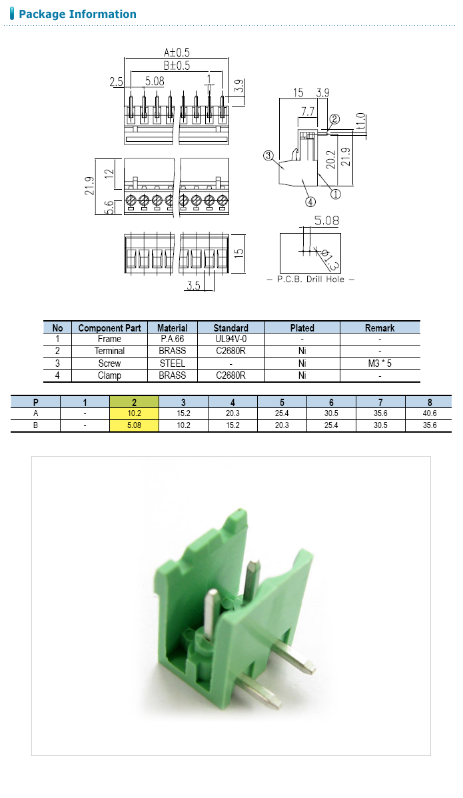
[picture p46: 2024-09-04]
doc/BR508.png

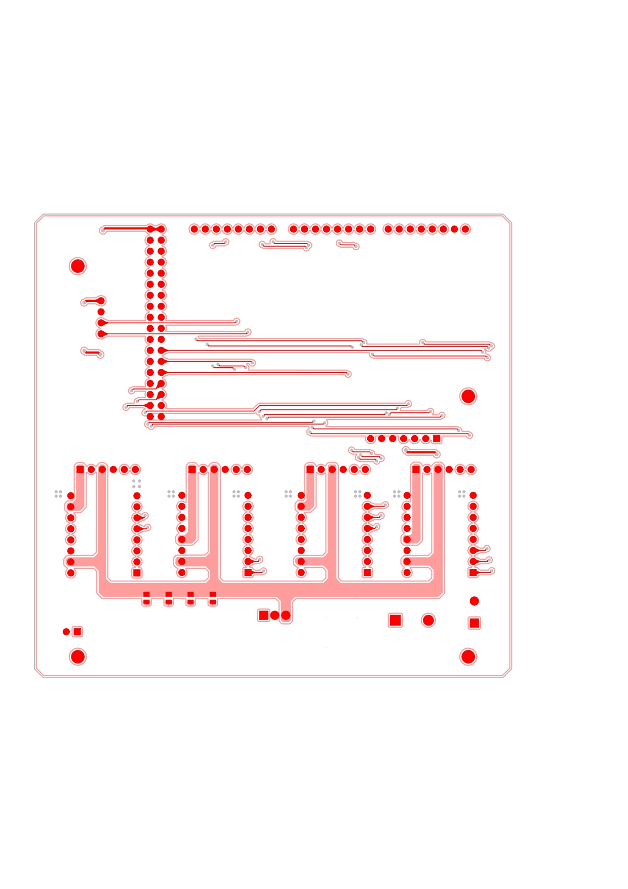
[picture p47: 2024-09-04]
img/car_PCB_page-0002.jpg

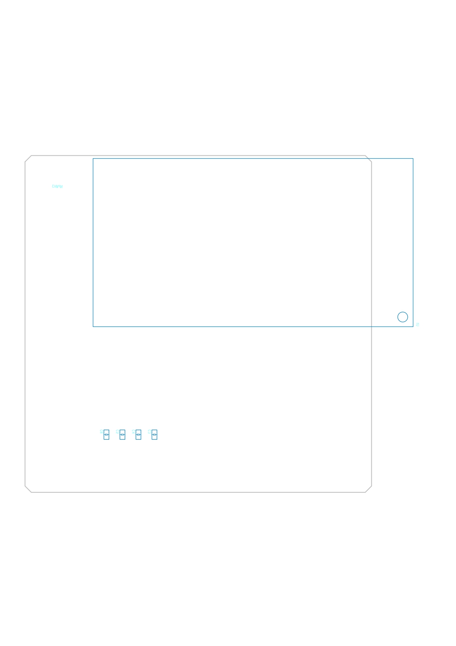
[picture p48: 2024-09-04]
img/car_PCB_page-0004.jpg

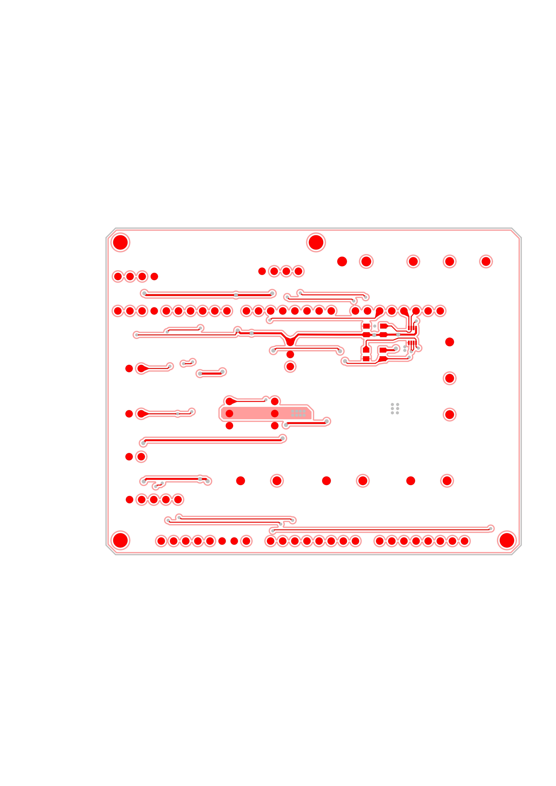
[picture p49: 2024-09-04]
img/control_box_PCB_page-0002.jpg

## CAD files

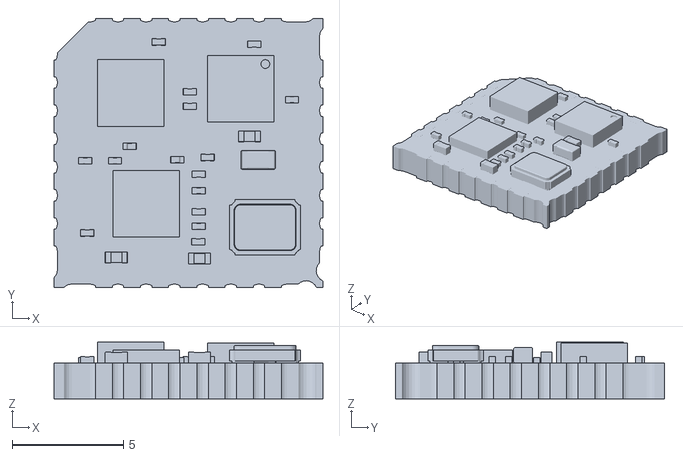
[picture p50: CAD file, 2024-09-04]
catkin_ws/src/xsens_ros_mti_driver/urdf/MTi_1.stl
12.1 x 12.1 x 2.56

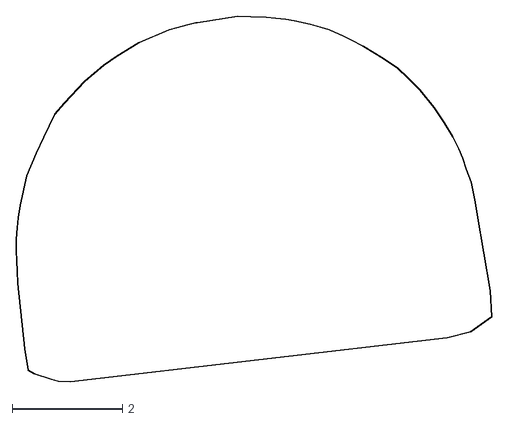
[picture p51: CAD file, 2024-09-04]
source/CloudPoint2CAD/convex_hull.dxf
8.61 x 6.62

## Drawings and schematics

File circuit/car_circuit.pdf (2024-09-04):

# IOREF 1 RESET 2 +3V3 3 +5V 4 GND 5 GND 6

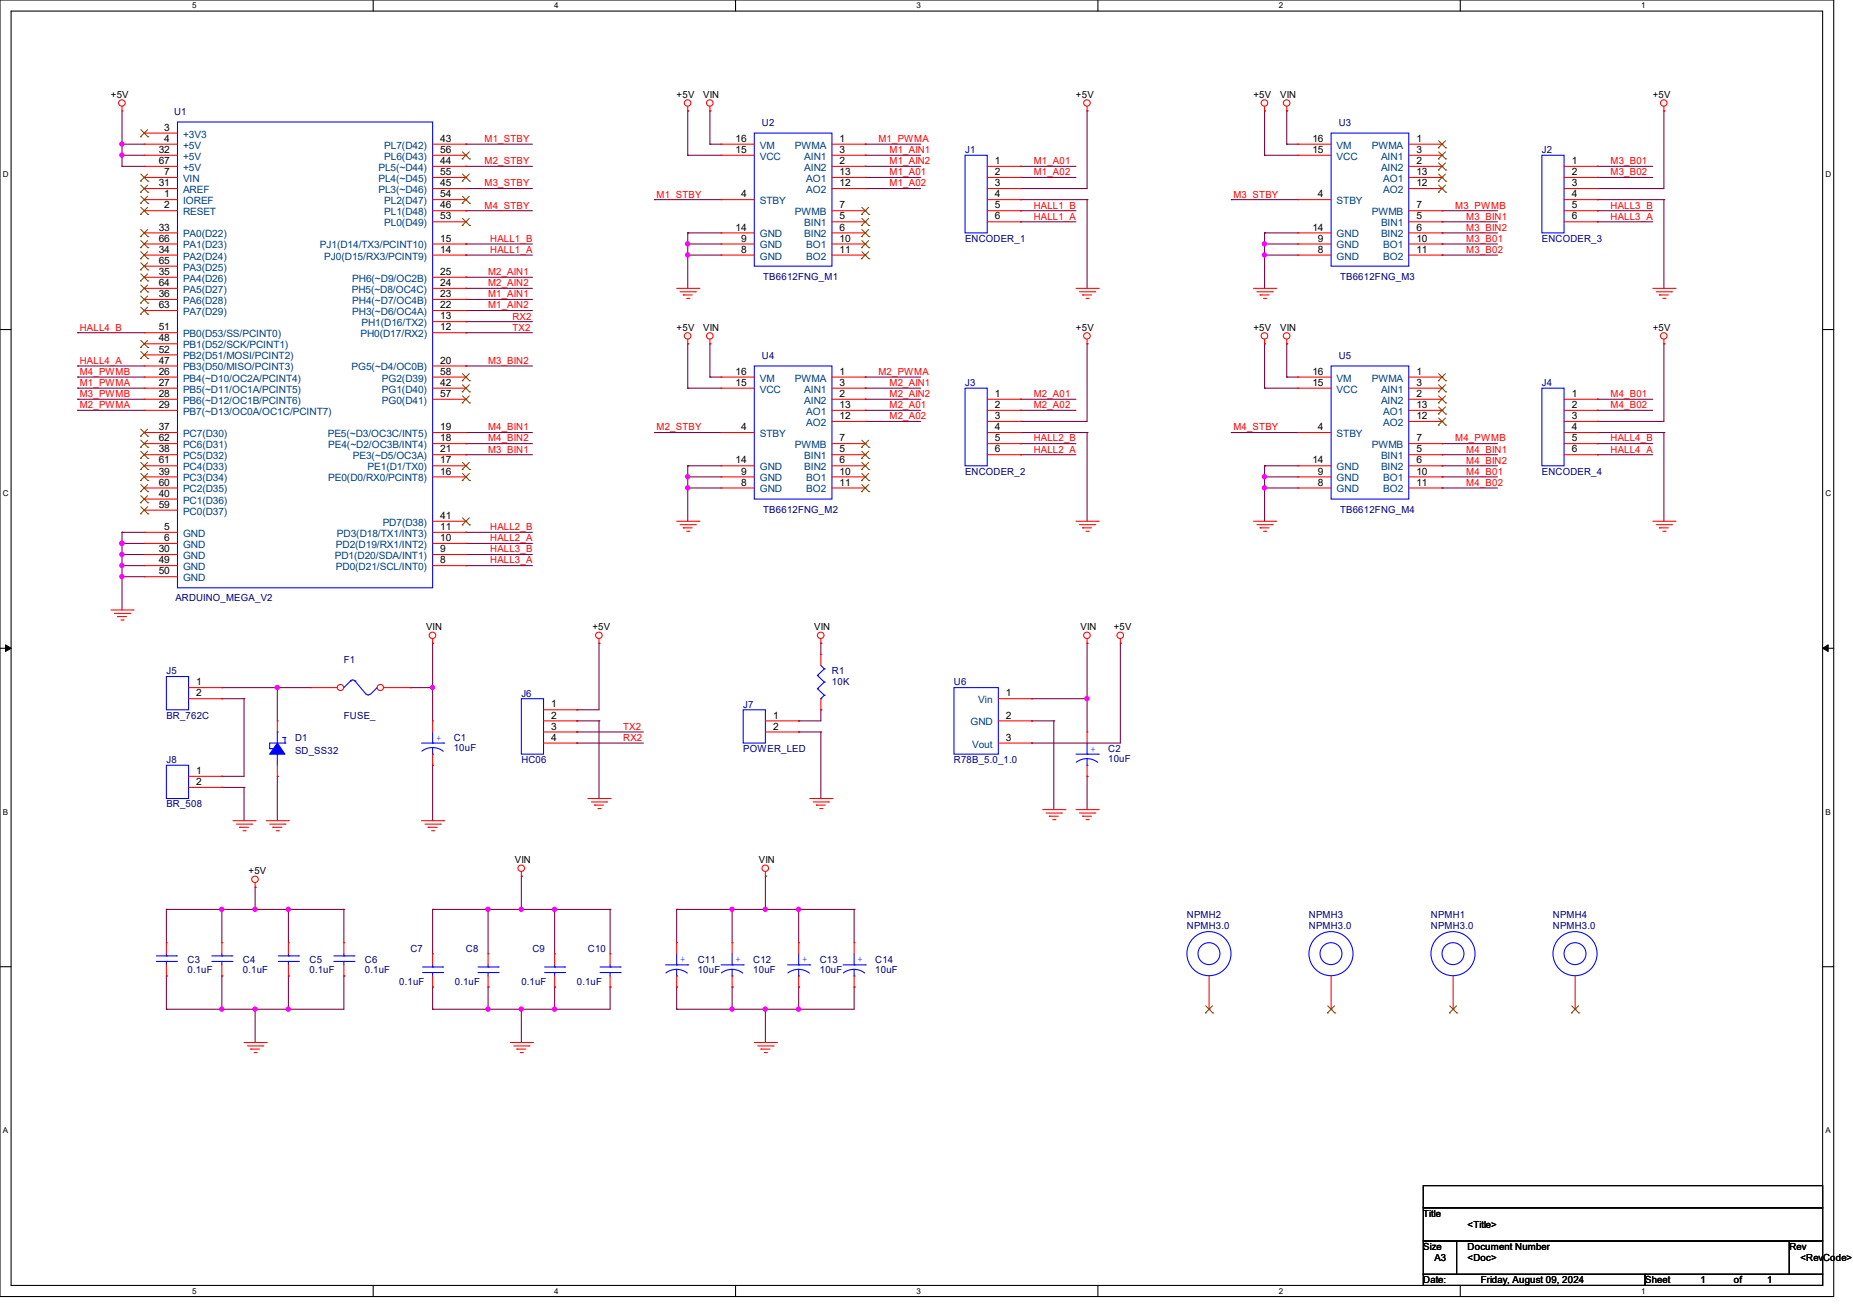
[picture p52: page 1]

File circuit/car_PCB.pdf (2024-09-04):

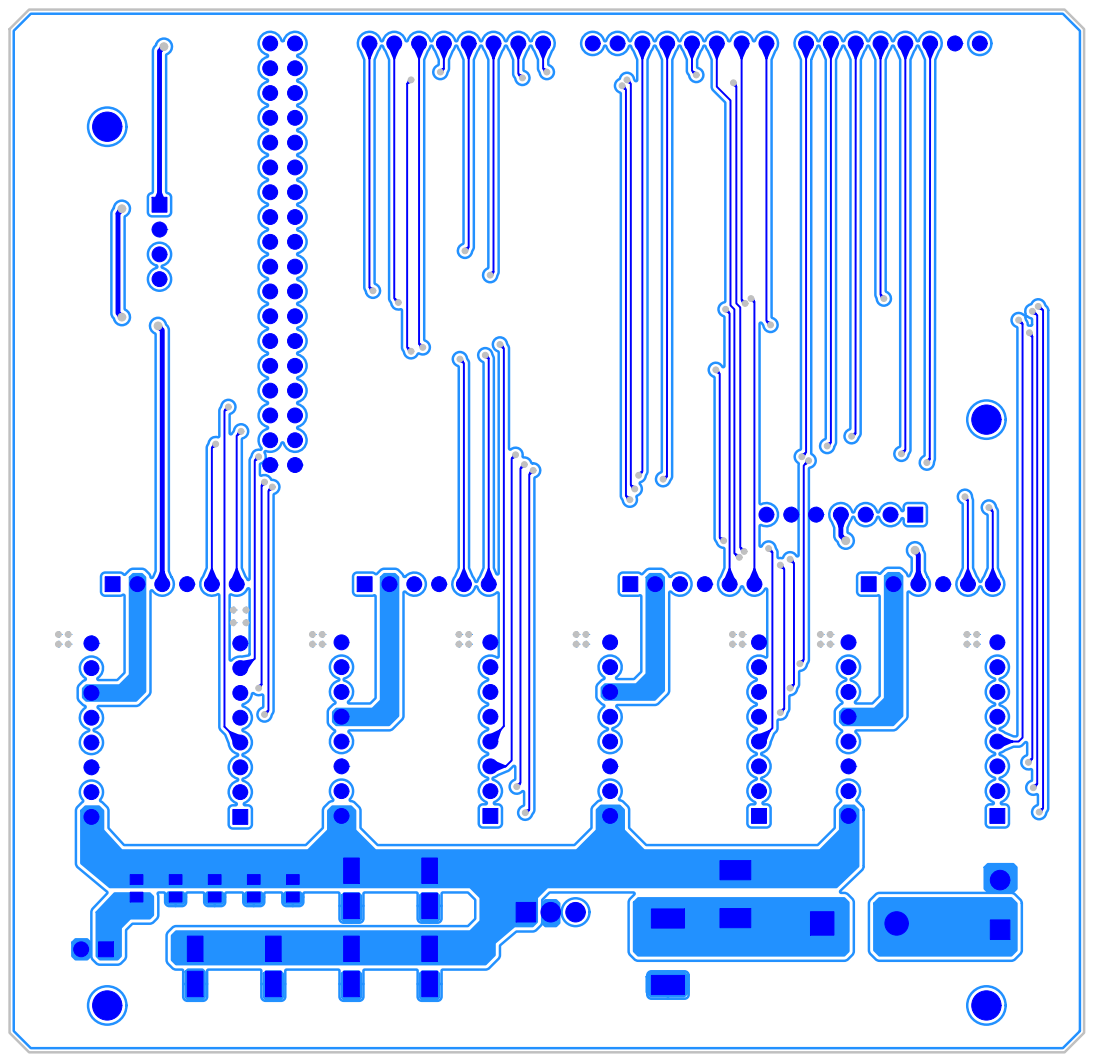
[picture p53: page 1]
C10C¹⁰x1 C¹⁰x2; C8C⁸x1 C⁸x2; C7C⁷x1; D1D¹x1 D¹x2; NPMH2NPMH²x1; NPMH1NPMH¹x1; NPMH3NPMH³x1; NPMH4NPMH⁴x1; R1R¹x1 R¹x2; U2U²x1 U²x2 U²x3 U²x4 U²x5 U²x6 U²x7 U²x9; U²x8 U²x10 U²x11 U²x12 U²x13 U²x14 U²x15; U3U³x1; U4U⁴x1; U5U⁵x1; U1U¹x7; U¹x6; U¹x5; U¹x4; U¹x3; U¹x2; U¹x1 U¹x32; U¹x8; U¹x9; U¹x10; U¹x11; U¹x12; U¹x13; U¹x14; U¹x15; U¹x16; U¹x17; U¹x18; U¹x19; U¹x20; U¹x21; U¹x22; U¹x23; U¹x24; U¹x25; U¹x26; U¹x27; U¹x28; U¹x29; U¹x30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

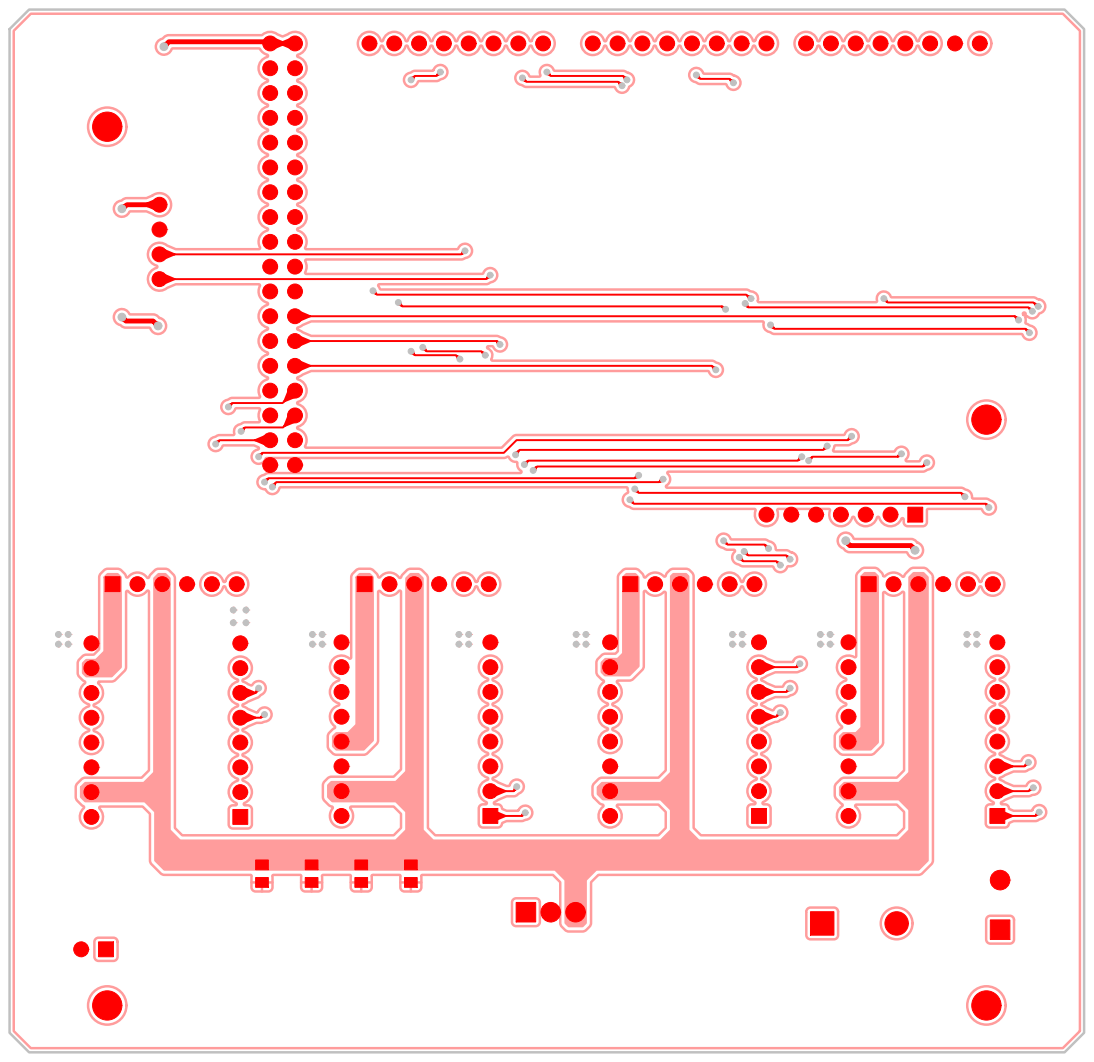
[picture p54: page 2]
C3C³x1; NPMH2NPMH²x1; NPMH1NPMH¹x1; NPMH3NPMH³x1; NPMH4NPMH⁴x1; U2U²x1 U²x2 U²x3 U²x4 U²x5 U²x6 U²x7 U²x9; U²x8 U²x10 U²x11 U²x12 U²x13 U²x14 U²x15; U3U³x1; U4U⁴x1; U5U⁵x1; U1U¹x7; U¹x6; U¹x5; U¹x4; U¹x3; U¹x2; U¹x1 U¹x32; U¹x8; U¹x9; U¹x10; U¹x11; U¹x12; U¹x13; U¹x14; U¹x15; U¹x16; U¹x17; U¹x18; U¹x19; U¹x20; U¹x21; U¹x22; U¹x23; U¹x24; U¹x25; U¹x26; U¹x27; U¹x28; U¹x29; U¹x30; U¹x31 U¹x33 U¹x34 U¹x35 U¹x36 U¹x37 U¹x38 U¹x39 U¹x40 U¹x41 U¹x42 U¹x43 U¹x44 U¹x45 U¹x46 U¹x47 U¹x48; U6U⁶x1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

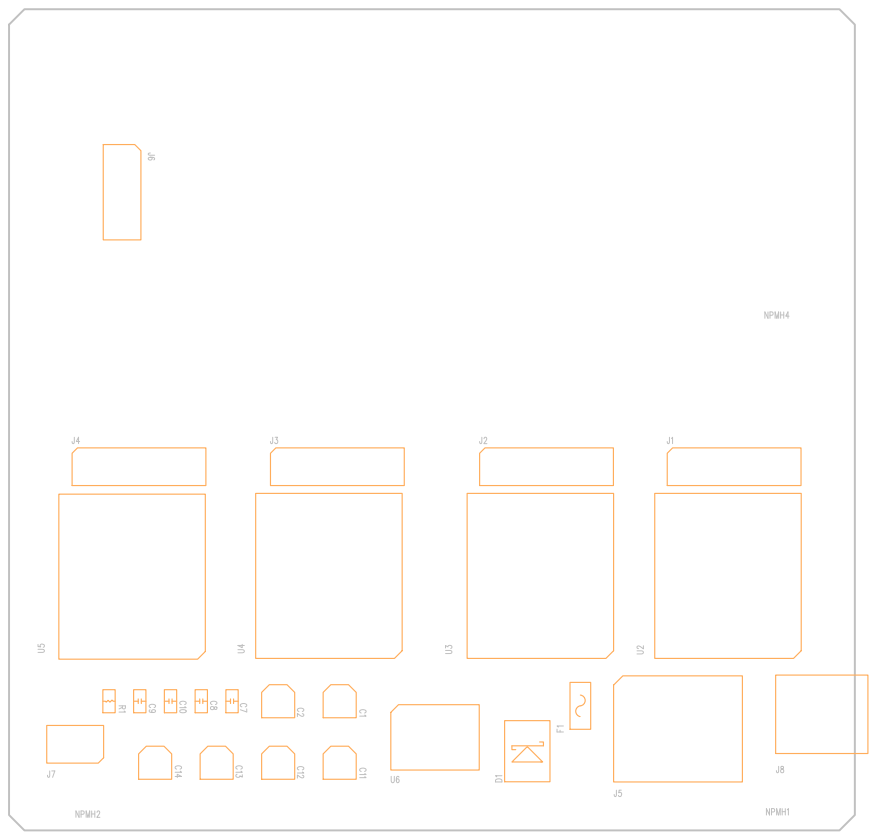
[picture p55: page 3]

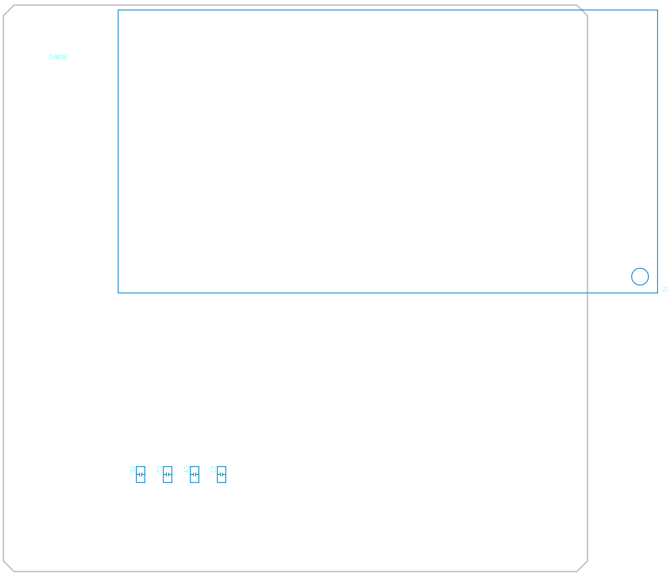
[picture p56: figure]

U1

U1

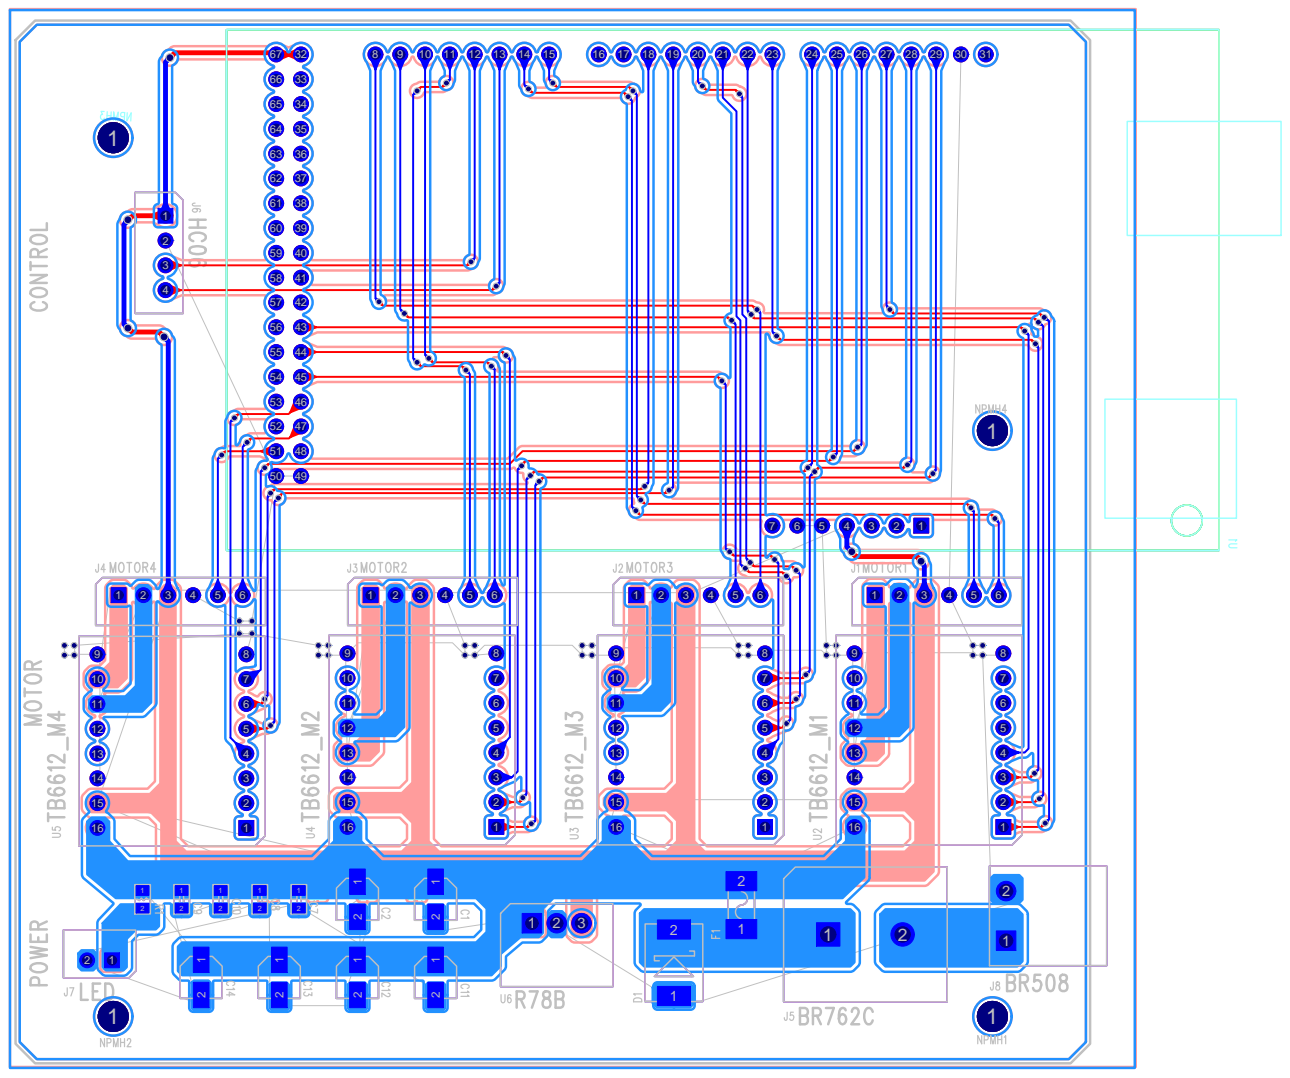
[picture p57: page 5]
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

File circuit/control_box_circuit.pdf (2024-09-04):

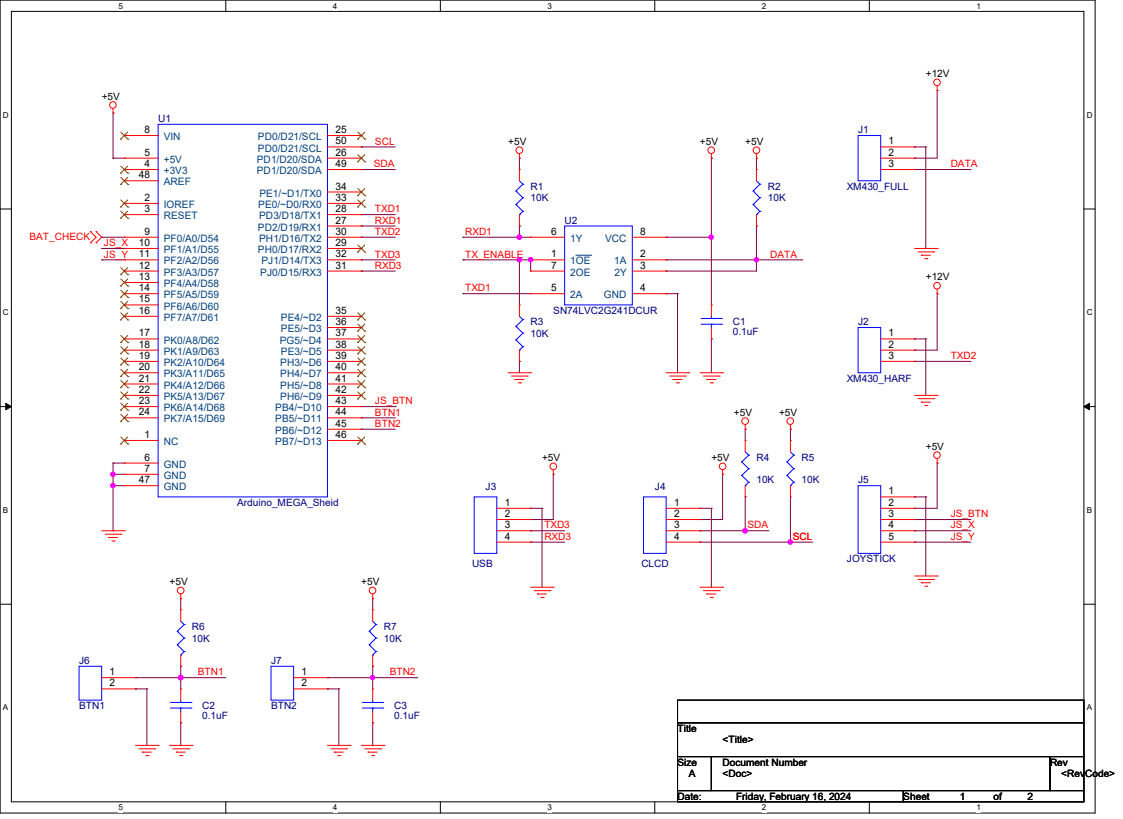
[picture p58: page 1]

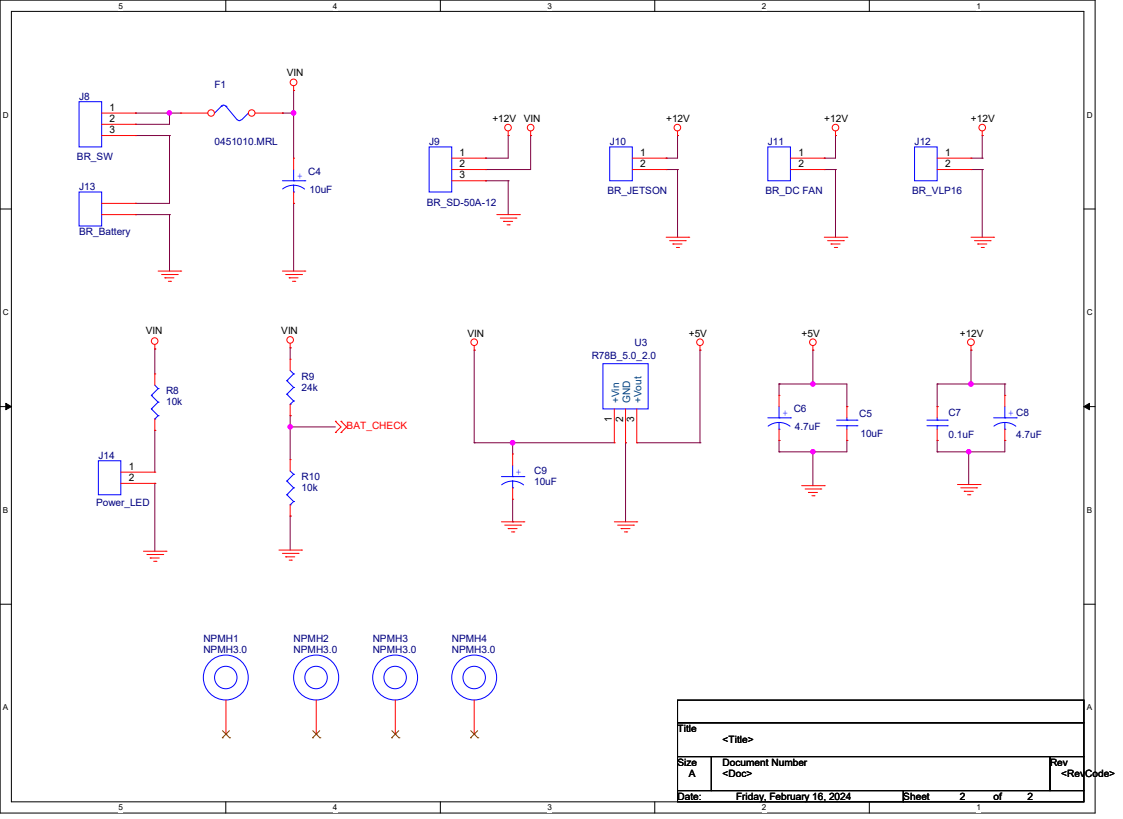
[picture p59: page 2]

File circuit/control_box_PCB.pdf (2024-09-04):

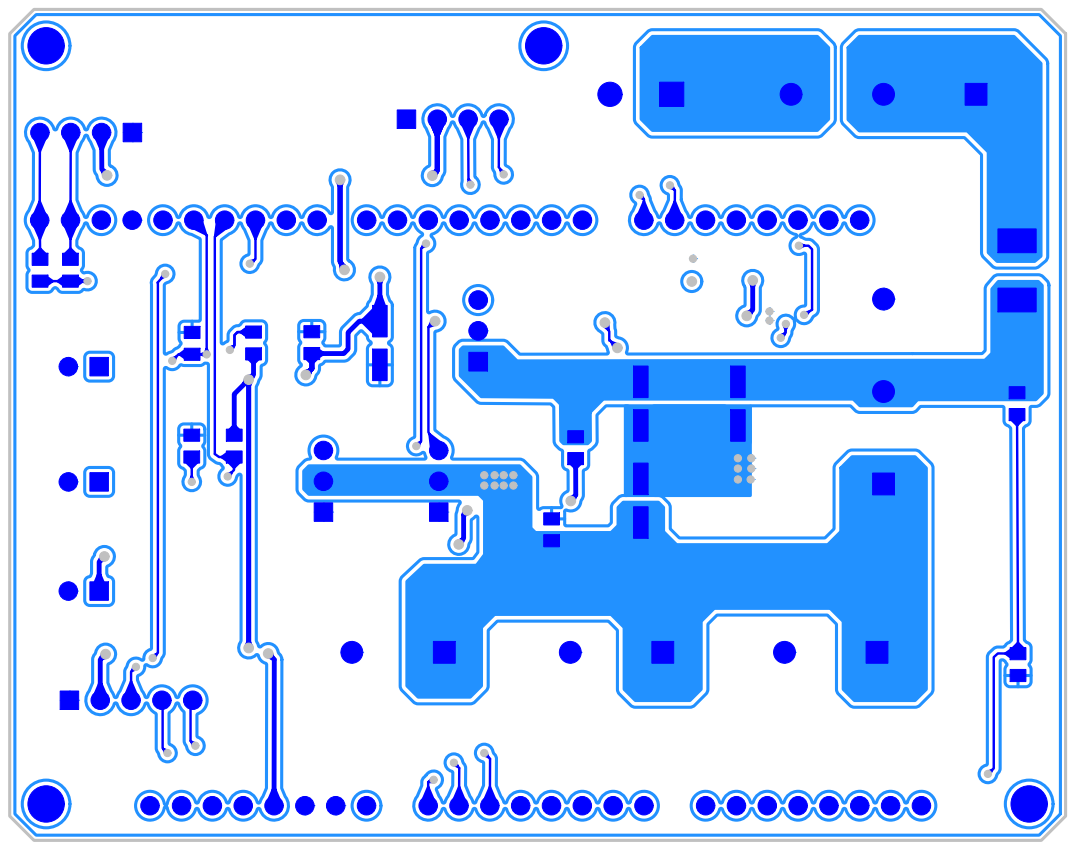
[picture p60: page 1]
C7C⁷x1 C⁷x2; C8C⁸x1 C⁸x2; C9C⁹x1 C⁹x2; NPMH1NPMH¹x1; NPMH2NPMH²x1; NPMH3NPMH³x1; NPMH4NPMH⁴x1; R6R⁶x1 R⁶x2; R5R⁵x1 R⁵x2; R9R⁹x1 R⁹x2; R7R⁷x1 R⁷x2; R10R¹⁰x1; U3U³x1 U³x2 U³x3; C2C²x1 C²x2; C3C³x1 C³x2; C5C⁵x1 C⁵x2; C4C⁴x1 C⁴x2; C6C⁶x1 C⁶x2; R4R⁴x1 R⁴x2; R8R⁸x1 R⁸x2

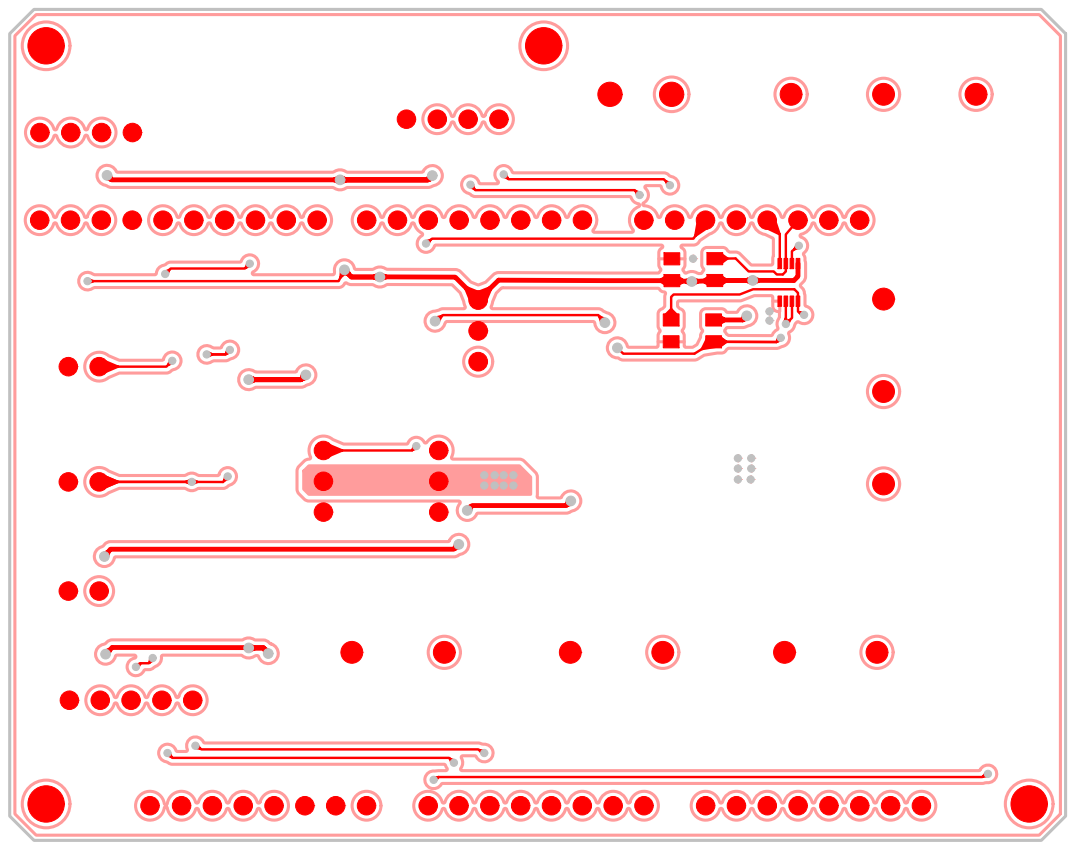
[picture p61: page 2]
NPMH1NPMH¹x1; NPMH2NPMH²x1; NPMH3NPMH³x1; NPMH4NPMH⁴x1; R1R¹x1 R¹x2; R2R²x1; U1U¹x1; U¹x2; U¹x3; U¹x4; U¹x5; U¹x6; U¹x7; U¹x8; U¹x9; U¹x10; U¹x11; U¹x12; U¹x13; U¹x14; U¹x15; U¹x16; U¹x17; U¹x18; U¹x19; U¹x20; U¹x21; U¹x22; U2U²x4; U²x3; U²x2; U²x1 U²x5; U²x6; U²x7; U²x8; U3U³x1 U³x2 U³x3; C1C¹x1 C¹x2

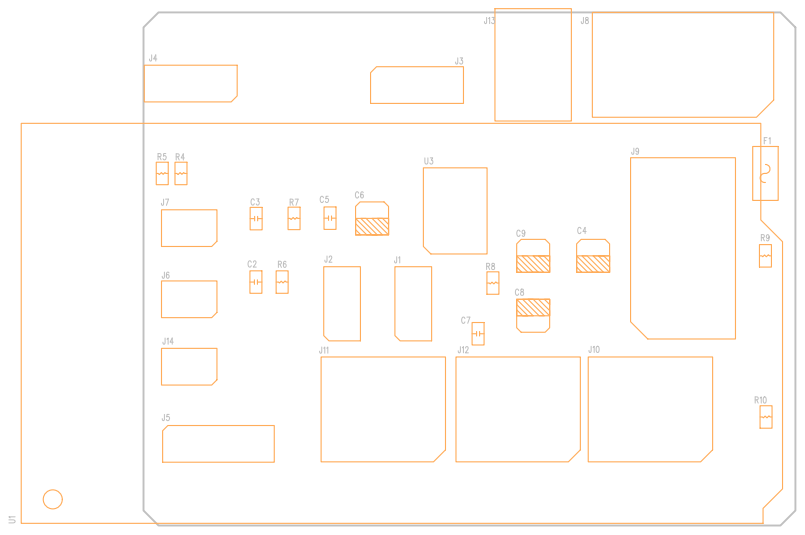
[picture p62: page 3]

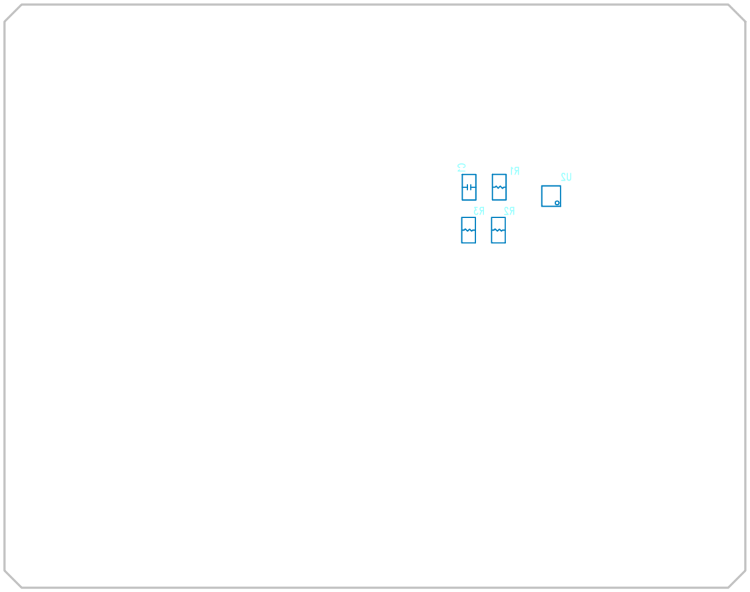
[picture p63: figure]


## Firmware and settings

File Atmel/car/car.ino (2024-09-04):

/*
 front
1     3
2     4
  back
*/
#define HALL1_A 15  //PCINT9
#define HOLL1_B 14  //PCINT10
#define IN1_1 6     //7
#define IN1_2 7     //6
#define PWM1 11
#define STBY1 42

#define HALL2_A 19  //INT2
#define HOLL2_B 18  //INT3
#define IN2_1 8     //9
#define IN2_2 9     //8
#define PWM2 13
#define STBY2 44

#define HALL3_A 21  //INT0
#define HOLL3_B 20  //INT1
#define IN3_1 5
#define IN3_2 4
#define PWM3 12
#define STBY3 46

#define HALL4_A 50  //PCINT3
#define HOLL4_B 53  //PCINT0
#define IN4_1 3
#define IN4_2 2
#define PWM4 10
#define STBY4 48

int new_speed1 = 0;
int new_speed2 = 0;
int new_speed3 = 0;
int new_speed4 = 0;

int max_speed = 255;
char bt_data = NULL;

byte gbpTxBuffer[128];
unsigned long auto_time;

enum PM  // Print Menu
{
  MAIN,
  MEASUREMENT,
  TUNNEL,
  CAVE,
  PROCESSING,
  SETTING,
  SETTING_ANGLE_MAX,
  SETTING_ANGLE_MIN,
  SELECT_USB,
};

void motor(int motor1_speed, int motor2_speed, int motor3_speed, int motor4_speed) {
  if (motor1_speed > 0) {
    digitalWrite(IN1_1, HIGH);
    digitalWrite(IN1_2, LOW);
    analogWrite(PWM1, motor1_speed);
  } else if (motor1_speed < 0) {
    new_speed1 = -motor1_speed;
    digitalWrite(IN1_1, LOW);
    digitalWrite(IN1_2, HIGH);
    analogWrite(PWM1, new_speed1);
  }
  if (motor2_speed > 0) {
    digitalWrite(IN2_1, HIGH);
    digitalWrite(IN2_2, LOW);
    analogWrite(PWM2, motor2_speed);
  } else if (motor2_speed < 0) {
    new_speed2 = -motor2_speed;
    digitalWrite(IN2_1, LOW);
    digitalWrite(IN2_2, HIGH);
    analogWrite(PWM2, new_speed2);
  }

  if (motor3_speed > 0) {
    digitalWrite(IN3_1, HIGH);
    digitalWrite(IN3_2, LOW);
    analogWrite(PWM3, motor3_speed);
  } else if (motor3_speed < 0) {
    new_speed3 = -motor3_speed;
    digitalWrite(IN3_1, LOW);
    digitalWrite(IN3_2, HIGH);
    analogWrite(PWM3, new_speed3);
  }
  if (motor4_speed > 0) {
    digitalWrite(IN4_1, HIGH);
    digitalWrite(IN4_2, LOW);
    analogWrite(PWM4, motor4_speed);
  } else if (motor4_speed < 0) {
    new_speed4 = -motor4_speed;
    digitalWrite(IN4_1, LOW);
    digitalWrite(IN4_2, HIGH);
    analogWrite(PWM4, new_speed4);
  }
}

void motor_stop() {
  analogWrite(PWM1, LOW);
  analogWrite(PWM2, LOW);
  analogWrite(PWM3, LOW);
  analogWrite(PWM4, LOW);
}

void send_data(Stream &serialport, byte buf_0, byte buf_1, byte buf_2) {
  gbpTxBuffer[0] = 0xff;
  gbpTxBuffer[1] = 0xff;
  gbpTxBuffer[2] = buf_0;
  gbpTxBuffer[3] = buf_1;
  gbpTxBuffer[4] = buf_2;

  char checksum = 0;
  for (int i = 2; i < 5; i++) {
    checksum += gbpTxBuffer[i];
  }
  gbpTxBuffer[5] = ~checksum;

  for (int i = 0; i < 6; i++) {
    serialport.write(gbpTxBuffer[i]);
    serialport.flush();
  }
}


void Packet() {
  if (Serial2.available()) {
    bt_data = Serial2.read();

    // Serial.print("bt_data : ");
    // Serial.println(bt_data);
  }

  if (bt_data == 'w') {  //직진
    motor(max_speed, max_speed, max_speed, max_speed);
  } else if (bt_data == 'q') {  //직좌회전
    motor(max_speed / 2, max_speed / 2, max_speed, max_speed);
  } else if (bt_data == 'e') {  //직우회전
    motor(max_speed, max_speed, max_speed / 2, max_speed / 2);
  } else if (bt_data == 's') {  //후진
    motor(-max_speed, -max_speed, -max_speed, -max_speed);
  } else if (bt_data == 'z') {  //후좌회전
    motor(-max_speed / 2, -max_speed / 2, -max_speed, -max_speed);
  } else if (bt_data == 'c') {  //후우회전
    motor(-max_speed, -max_speed, -max_speed / 2, -max_speed / 2);
  } else if (bt_data == 'a') {  //제자리 좌회전
    motor(-max_speed, -max_speed, max_speed, max_speed);
  } else if (bt_data == 'd') {  //제자리 우회전
    motor(max_speed, max_speed, -max_speed, -max_speed);
  } else if (bt_data == 'n') {  //정지
    motor_stop();
  }

  //Jetson Orin Nano
  else if (bt_data == '1') {  //터널 측정모드
    send_data(Serial, 0x02, 0x00, 0x02);
    auto_time = millis();
  }

  else if (bt_data == '2') {
    // SEND TUNNEL 측정 시작, PROCESSING
    send_data(Serial, 0x02, 0x00, 0x03);
  }

  else if (bt_data == '3') {  //CAVE 측정모드
    // SEND CAVE 측정 시작
    send_data(Serial, 0x02, 0x00, 0x05);
    auto_time = millis();
  }

  else if (bt_data == '4') {  //CAVE 측정시작
    //cave측정 시작
    send_data(Serial, 0x02, 0x00, 0x07);
  }

  else if (bt_data == '5') {  //CAVE 측정정지
    send_data(Serial, 0x02, 0x00, 0x04);
    // SEND CAVE 측정 중지
    send_data(Serial, 0x03, 0x00, 0x01);
    // SEND USB 연결 유지
  } else
    bt_data = NULL;
}

void motor_init() {
  pinMode(IN1_1, OUTPUT);
  pinMode(IN1_2, OUTPUT);
  pinMode(IN2_1, OUTPUT);
  pinMode(IN2_2, OUTPUT);
  pinMode(IN3_1, OUTPUT);
  pinMode(IN3_2, OUTPUT);
  pinMode(IN4_1, OUTPUT);
  pinMode(IN4_2, OUTPUT);

  pinMode(STBY1, OUTPUT);
  pinMode(STBY2, OUTPUT);
  pinMode(STBY3, OUTPUT);
  pinMode(STBY4, OUTPUT);

  digitalWrite(STBY1, HIGH);
  digitalWrite(STBY2, HIGH);
  digitalWrite(STBY3, HIGH);
  digitalWrite(STBY4, HIGH);

  pinMode(PWM1, OUTPUT);
  pinMode(PWM2, OUTPUT);
  pinMode(PWM3, OUTPUT);
  pinMode(PWM2, OUTPUT);
}


void setup() {
  motor_init();
  Serial.begin(1000000);
  Serial2.begin(9600);
}

void loop() {

  Packet();
}

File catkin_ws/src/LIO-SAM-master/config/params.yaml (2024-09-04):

lio_sam:

  # Topics
  pointCloudTopic: "/velodyne_points"               # Point cloud data
  imuTopic: "/imu/data"                         # IMU data
  odomTopic: "odometry/imu"                   # IMU pre-preintegration odometry, same frequency as IMU
  gpsTopic: "odometry/gpsz"                   # GPS odometry topic from navsat, see module_navsat.launch file

  # Frames
  lidarFrame: "base_link"
  baselinkFrame: "base_link"
  odometryFrame: "odom"
  mapFrame: "map"

  # GPS Settings
  useImuHeadingInitialization: false           # if using GPS data, set to "true"
  useGpsElevation: false                      # if GPS elevation is bad, set to "false"
  gpsCovThreshold: 2.0                        # m^2, threshold for using GPS data
  poseCovThreshold: 25.0                      # m^2, threshold for using GPS data
  
  # Export settings
  savePCD: true                              # https://github.com/TixiaoShan/LIO-SAM/issues/3
  savePCDDirectory: "/slam3/USB/2024-08-16-23-16-32/LOAM_PCD"          
  # in your home folder, starts and ends with "/". Warning: the code deletes "LOAM" folder then recreates it. See "mapOptimization" for implementation

  # Sensor Settings
  sensor: velodyne                            # lidar sensor type, 'velodyne' or 'ouster' or 'livox'
  N_SCAN: 16                                  # number of lidar channel (i.e., Velodyne/Ouster: 16, 32, 64, 128, Livox Horizon: 6)
  Horizon_SCAN: 1800                          # lidar horizontal resolution (Velodyne:1800, Ouster:512,1024,2048, Livox Horizon: 4000)
  downsampleRate: 1                           # default: 1. Downsample your data if too many points. i.e., 16 = 64 / 4, 16 = 16 / 1
  lidarMinRange: 0.01                          # default: 1.0, minimum lidar range to be used
  lidarMaxRange: 100.0                       # default: 1000.0, maximum lidar range to be used

  # IMU Settings
  imuAccNoise: 3.9939570888238808e-03
  imuGyrNoise: 1.5636343949698187e-03
  imuAccBiasN: 6.4356659353532566e-05
  imuGyrBiasN: 3.5640318696367613e-05
  imuGravity: 9.80511
  imuRPYWeight: 0.001

  # Extrinsics: T_lb (lidar -> imu)
  extrinsicTrans: [0.0, 0.0, 0.0]
  extrinsicRot: [1, 0, 0,
                  0, -1, 0,
                  0, 0, -1]
  extrinsicRPY: [1, 0, 0,
                 0, -1, 0,
                 0, 0, -1]
  # extrinsicRot: [1, 0, 0,
  #                 0, 1, 0,
  #                 0, 0, 1]
  # extrinsicRPY: [1, 0, 0,
  #                 0, 1, 0,
  #                 0, 0, 1]

  # LOAM feature threshold
  edgeThreshold: 1.0
  surfThreshold: 0.1
  edgeFeatureMinValidNum: 10
  surfFeatureMinValidNum: 100

  # voxel filter paprams
  odometrySurfLeafSize: 0.2                     # default: 0.4 - outdoor, 0.2 - indoor
  mappingCornerLeafSize: 0.1                    # default: 0.2 - outdoor, 0.1 - indoor
  mappingSurfLeafSize: 0.2                      # default: 0.4 - outdoor, 0.2 - indoor

  # robot motion constraint (in case you are using a 2D robot)
  z_tollerance: 1000                            # meters
  rotation_tollerance: 1000                     # radians

  # CPU Params
  numberOfCores: 6                              # number of cores for mapping optimization
  mappingProcessInterval: 0.15                  # seconds, regulate mapping frequency

  # Surrounding map
  surroundingkeyframeAddingDistThreshold: 1.0   # meters, regulate keyframe adding threshold
  surroundingkeyframeAddingAngleThreshold: 0.2  # radians, regulate keyframe adding threshold
  surroundingKeyframeDensity: 2.0               # meters, downsample surrounding keyframe poses   
  surroundingKeyframeSearchRadius: 50.0         # meters, within n meters scan-to-map optimization (when loop closure disabled)

  # Loop closure
  loopClosureEnableFlag: true
  loopClosureFrequency: 1.0                     # Hz, regulate loop closure constraint add frequency
  surroundingKeyframeSize: 50                   # submap size (when loop closure enabled)
  historyKeyframeSearchRadius: 15.0             # meters, key frame that is within n meters from current pose will be considerd for loop closure
  historyKeyframeSearchTimeDiff: 30.0           # seconds, key frame that is n seconds older will be considered for loop closure
  historyKeyframeSearchNum: 25                  # number of hostory key frames will be fused into a submap for loop closure
  historyKeyframeFitnessScore: 0.3              # icp threshold, the smaller the better alignment

  # Visualization
  globalMapVisualizationSearchRadius: 1000.0    # meters, global map visualization radius
  globalMapVisualizationPoseDensity: 10.0       # meters, global map visualization keyframe density
  globalMapVisualizationLeafSize: 1.0           # meters, global map visualization cloud density
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

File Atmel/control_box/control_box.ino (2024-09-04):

// 2024-04-10
#include <LiquidCrystal_I2C.h>

#define tx_enable 2
#define SN74LV_TX \
  digitalWrite(tx_enable, HIGH); \
  delayMicroseconds(10);
#define SN74LV_RX \
  digitalWrite(tx_enable, LOW); \
  delayMicroseconds(10);

float velocity = 5;
int ori_angle_min = 180;
int ori_angle_max = 180;

enum SN  // State nums
{
  ERROR,
  FAIL_LIDAR,
  FAIL_IMU,
  FAIL_USB,
  FAIL_LIDAR_IMU_USB,
  FAIL_LIDAR_IMU,
  FAIL_LIDAR_USB,
  FAIL_IMU_USB,
  BOOT,
  GOOD,
};

enum PM  // Print Menu
{
  MAIN,
  MEASUREMENT,
  TUNNEL,
  CAVE,
  PROCESSING,
  SETTING,
  SETTING_ANGLE_MAX,
  SETTING_ANGLE_MIN,
  SELECT_USB,
};

void send_data(Stream &serialport, byte buf_0, byte buf_1, byte buf_2);

class str {
  private:
    char *pstring;
    int str_len = 0;
  public:
    str(int val);
    str(int val, int space_buffer);
    ~str();
    str(const char c[]);
    int len(void);
    const char* string(void);
};

str::str(int val) {
  int temp_val = val;
  int cnt = 1;
  while (temp_val != 0) {
    temp_val = temp_val / 10;
    ++cnt;
  }
  str_len = cnt;

  pstring = new char[str_len + 1];
  sprintf(pstring, "%d  ", val);
  pstring[str_len] = NULL;
}

str::str(int val, int space_buffer) {
  int temp_val = val;
  int cnt = 1;
  while (temp_val != 0) {
    temp_val = temp_val / 10;
    ++cnt;
  }
  str_len = cnt;

  pstring = new char[str_len + 1 + space_buffer];
  sprintf(pstring, "%d  ", val);
  pstring[str_len + space_buffer] = NULL;
}

int str::len(void) {
  return str_len;
}

const char* str::string(void) {
  return pstring;
}

str::~str() {
  delete[] pstring;
}

// 객체이름을 lcd로 선언 I2C 주소값을 0x27로 설정, 16 문자 2줄 디스플레이
// 만약 lcd가 출력이 안된다면, 주소값을 0x27 혹은 0x3F로 수정
class CONTROL {
  private:
    bool jetson_state = false;
    bool imu_state = false;
    bool lidar_state = false;
    bool USB_state = false;

    bool toogle = true;
    int col;
    int row;

    int bat = 100;
    int stat = 4;
    int page = MAIN;
    int cursor = 3;
    int proc_g = 0;

    int angle_min = 180;
    int angle_max = 180;

    int js_x = 1;
    int js_y = 1;

    int cursor_cnt = 0;
    int capture_cnt = 0;

    unsigned long auto_time;
    LiquidCrystal_I2C *lcd;
  public:
    CONTROL(void);
    void print_menu(void);
    void print_state(int battery, int state);
    void print_str(const char c[]);
    void set_cursor(int _col, int _row);
    void sector_clear(char start_row, char start_col, char cnt);
    int cur_range(int page, int select);
    void get_angle(int& A_min, int& A_max);
    void angle_print(int max_cursor, int min_cursor);
    void control(Stream &serialport, int joystick_x, int joystick_y, int joystick_btn, int press_btn);
    void serial_data_state(int instruction, int value, int state);
    bool jetson_state_return(void);
};

CONTROL::CONTROL(void) {
  col = 0;
  row = 0;
  LiquidCrystal_I2C lcd_init(0x27, 20, 4);

  lcd = &lcd_init;
  lcd->init(); // lcd 시작
  lcd->backlight(); // lcd 백라이트 on
  set_cursor(col, row);
}

bool CONTROL::jetson_state_return(void) {
  return jetson_state;
}

void CONTROL::print_state(int battery, int state) {
  /*
    state
    enum SN  // State nums
    {
    ERROR,
    FAIL_LIDAR,
    FAIL_IMU,
    FAIL_USB,
    FAIL_LIDAR_IMU_USB,
    FAIL_LIDAR_IMU,
    BOOT,
    GOOD,
    FAIL_USB,
    };
  */
  if (bat != battery) {
    sector_clear(8, 0, 12);
    bat = battery;
  }
  str bat_s(bat);

  set_cursor(0, 0);
  print_str("BATTERY:");

  set_cursor(20 - (bat_s.len() + 1), 0);
  print_str(bat_s.string());
  print_str("%");

  if (stat != state && state != -1) {
    sector_clear(6, 1, 14);
    stat = state;
  }
  else {
    return;
  }
  set_cursor(0, 1);
  print_str("STATE:");
  switch (stat) {
    case FAIL_LIDAR:
      set_cursor(20 - 11, 1);
      print_str("FAIL(LIDAR)");
      break;
    case FAIL_IMU:
      set_cursor(20 - 9, 1);
      print_str("FAIL(IMU)");
      break;
    case FAIL_USB:
      set_cursor(20 - 9, 1);
      print_str("FAIL(USB)");
      break;
    case FAIL_LIDAR_IMU_USB:
      set_cursor(20 - 13, 1);
      print_str("FAIL(L, I, U)");
      break;
    case FAIL_LIDAR_IMU:
      set_cursor(20 - 10, 1);
      print_str("FAIL(L, I)");
      break;
    case FAIL_LIDAR_USB:
      set_cursor(20 - 10, 1);
      print_str("FAIL(L, U)");
      break;
    case FAIL_IMU_USB:
      set_cursor(20 - 10, 1);
      print_str("FAIL(I, U)");
      break;
    case BOOT:
      set_cursor(20 - 7, 1);
      print_str("BOOTING");
      break;
    case GOOD:
      set_cursor(20 - 4, 1);
      print_str("GOOD");
      break;
    default:
      set_cursor(20 - 5, 1);
      print_str("ERROR");
  }
}

int CONTROL::cur_range(int page, int select) {
  if (page == MAIN || page == MEASUREMENT || page == TUNNEL || page == CAVE) {
    if (select < 2)
      return 2;
    else if (select > 3)
      return 3;
  } else if (page == PROCESSING) {
    return -1;
  }
}

void CONTROL::angle_print(int max_cursor, int min_cursor) {
  str angle_max_s(angle_max, 2);
  str angle_min_s(angle_min, 2);

  if (max_cursor != -1) {
    set_cursor(11, max_cursor);
    print_str(angle_max_s.string());
  }
  if (min_cursor != -1) {
    set_cursor(11, min_cursor);
    print_str(angle_min_s.string());
  }
}

void CONTROL::get_angle(int& A_min, int& A_max) {
  A_min = angle_min;
  A_max = angle_max;
}
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
